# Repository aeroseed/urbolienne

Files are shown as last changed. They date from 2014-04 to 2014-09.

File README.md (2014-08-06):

urbolienne
==========

You will find on this webpage all the documents relative to the [AeroSeeD](http://www.aeroseed.com)'s wind turbine (the "urbolienne").

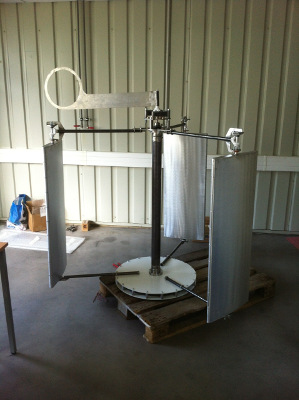
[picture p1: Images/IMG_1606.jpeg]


The Urbolienne Project website : http://www.energinov.org

Licenses
--------

<a href="http://www.oshwa.org/definition/">Prototype of urbolienne</a>

The urbolienne's 2D drawings and 3D models are made available under the terms of the TAPR Open Hardware License (http://tapr.org/ohl). See the "TAPR license.txt" file that accompanies this distribution for the full text of the license.

The urbolienne's documentation is made available under the terms of the GNU Free Documentation Licence (https://www.gnu.org/licenses/fdl.html). See the "GNU Free Documentation License.txt" file that accompanies this distribution for the full text of the license.

Disclaimer
----------

This hardware/software is provided "as is", and you use the hardware/software at your own risk. Under no circumstances shall any author be liable for direct, indirect, special, incidental, or consequential damages resulting from the use, misuse, or inability to use this hardware/software, even if the authors have been advised of the possibility of such damages.

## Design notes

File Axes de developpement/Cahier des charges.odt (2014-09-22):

Cahier des charges fonctionnel

pour la mise au point d'un produit commercialisable de l'

Eolienne à orientation de pale dynamique

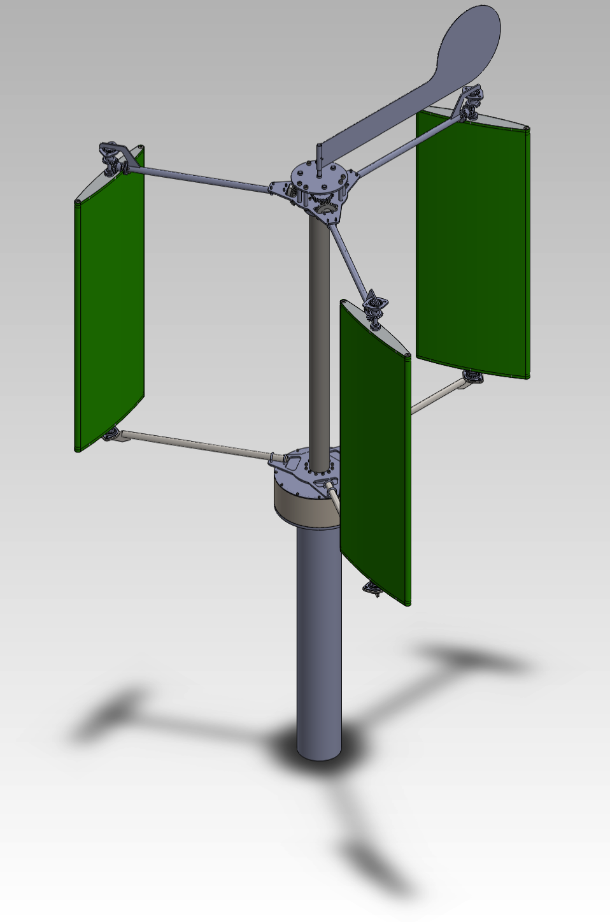
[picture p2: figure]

1. Objet du document :

Ce document décrit les axes de développements pour l'obtention d'un produit commercialisable.

LICENCE :

Licenced under the GNU Free documentation Licence (https://www.gnu.org/licenses/fdl.fr.html)

Cahier des charges

Théophile BRESSON - AeroSeeD Page 1 sur 1 03/07/2014

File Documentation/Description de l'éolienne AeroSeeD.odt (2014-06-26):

Copyright (C) 2014 Théophile BRESSON - AeroSeeD.

Permission is granted to copy, distribute and/or modify this document under the terms of the GNU Free Documentation License, Version 1.3 or any later version published by the Free Software Foundation;

with no Invariant Sections, no Front-Cover Texts, and no Back-Cover Texts.

A copy of the license is included in the section entitled "GNU Free Documentation License".

Éolienne à orientation de pale dynamique


1. Objet du document :

Ce document décrit ce qui caractérise l'éolienne d'AeroSeeD...

2. Idée :

L’éolienne proposée présente l’intérêt suivant :

Cette éolienne est capable de produire de l’énergie avec un rendement plus élevé que les éoliennes actuelles dans des conditions d'installation en écoulement turbulent (villes ou villages).

Nous avons abouti à une éolienne à axe vertical dont les pales lors de leur rotation s’orientent par rapport au vent de manière à fournir à l’éolienne le maximum de puissance.

3. Historique du développement

Courant 2005 : discussions avec Richard SORRENTINO à propos d’une éolienne à pas variable du même type que celle déjà existante (voir brevet nommé précédemment).

04/08/2007 : réalisation d’une maquette en lego du système pour observer le fonctionnement et test à l’aide d’un ventilateur.

19/08/2007 : premier tableau grossier permettant le calcul de la puissance délivrée par l’éolienne en fonction de ses dimensions et de la vitesse du vent.

10/07/2008 : réalisation d’une première CAO de l’éolienne afin de se confronter à la faisabilité du projet et terme mécanique.
Réalisation d’un premier chiffrage du modèle CAO de manière à quantifier la fabrication du prototype, il manque alors toute la partie électrique de puissance.

Courant été 2008 : découverte de l’idée d’une cinématique de pale calée de manière à maximiser la puissance.

05/12/2008 : première simulation fluide menée via le logiciel Fluent d’ANSYS.

18/04/2009 : développement d’un logiciel en C++ de manière à quantifier le gain théorique que permet ce calage de la pale et apparition des premières théories cinématiques du mouvement (adaptation d’un mouvement sinusoïdal de la pale autour de sa position « standard »).

12/05/2010 : deuxième simulation fluide de l’éolienne de manière à prendre en compte les modifications apportées et quantifier les turbulences générées par la pale amont sur la pale aval.

10/03/2011 : réalisation d’un deuxième tableau de manière à quantifier la puissance produite par l’éolienne avec et sans l’innovation. Comparatif permettant de montrer une multiplication de la production énergétique par deux (2).

12/03/2011 : réalisation d’un premier modèle de CAO destiné à être le support des plans de fabrication du premier prototype.
L’entraînement des pales sera réalisé par un système de pignon/chaîne/roue dentée elliptique.
Ajout d’un système de mise en sécurité de l’éolienne reposant sur le principe du régulateur de WATT.

29/07/2011 : réalisation d’une nouvelle simulation fluide. Celle-ci permet de quantifier avec une bonne approximation la puissance produite par l’éolienne. Nous avons ainsi pu estimer son rendement aérodynamique théorique dans l’état « brut » (sans optimisation de profil de pale ni de géométrie).

24/11/2011 : modification de la conception du modèle de CAO de manière à le simplifier et le rendre plus robuste.
Modification du système d’entraînement des pales qui sera réalisé par un jeu d’engrenage conique ainsi que d’engrenage elliptique. L’ellipse étant déterminée de manière à être la plus proche de la cinématique optimale et ainsi maximiser la puissance produite (voir Annexe 2).
Modification du système de mise en sécurité.

Début 2014 : suite au choix de développer l'éolienne sous licence libre, les outils nécessaires au support de la communauté ont été mis en place et étayés.

4. Description :

L'éolienne est équipée d’une voilure tournante comprenant :

- Un axe principal (vertical) permettant le guidage du rotor ;
- Une girouette ;
- 3 pales ;
- 3 bras inférieurs et 3 bras supérieurs de maintien des pales ;
- L'orientation des pales est imposée par la girouette via un système d'engrenages et d'arbres de transmission ;
- Un alternateur, pour transformer l'énergie mécanique en énergie électrique.

La transmission de chaque pale est réalisée de manière à ce que celle-ci effectue une demi révolution autour de son axe lorsque le rotor réalise une révolution autour de son axe.

L’orientation de chaque pale par rapport à la girouette est réalisée de manière à maximiser la puissance de cette pale en chaque point lors de sa révolution autour du rotor.

5. Théorie du mouvement :

L’orientation théorique de la pale à chaque position lors de sa rotation autour du rotor est déterminée par un tableau combiné à une simulation d’écoulement fluide de manière à connaître la trajectoire de la pale.
Le rapport moyen sur un tour de la rotation de la pale par rapport à celle du rotor est égal à un demi (0,5).
Le rapport instantané à chaque position de la pale lors de sa révolution autour de l’éolienne entre la pale et le rotor, varie entre 0,25 et 4 et plus précisément dans l’état de nos recherche entre 0,4 et 2,5.

La partie difficile ayant été de déterminer un mécanisme réel permettant de caler parfaitement à cette cinématique et sinon de s’en approcher le plus possible.

Les parties suivantes vont présenter à la fois une description de l’idée proprement dite et sujette de ce document, ainsi que les choix technologiques que nous avons posés afin de fabriquer un prototype nous permettant de valider cette idée.

6. Théorie aérodynamique :

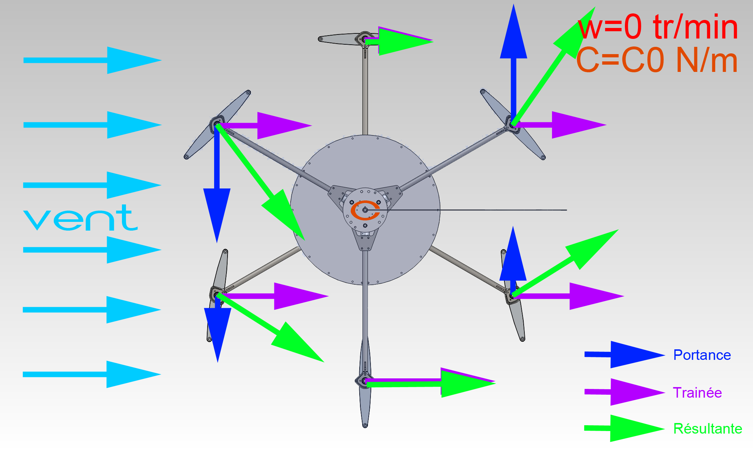
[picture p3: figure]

Bilan des efforts appliqués sur la pale suivant plusieurs positions lors de sa révolution autour de l'axe pour une vitesse de vent Vn (m/s) et pour une vitesse de rotation nulle.

Cette configuration permet d'obtenir un couple minium permettant à l'éolienne de commencer à tourner lorsque le vent se lève.

Ensuite, c'est l'orientation des pales spécialement étudié par AeroSeeD qui permet d'obtenir une vitesse nominale importante (la pale initialement poussée allant à la même vitesse que le vent). Tout en conservant un couple résultant par portance de la pale lors de sa trajectoire transverse (voir images ci-après).

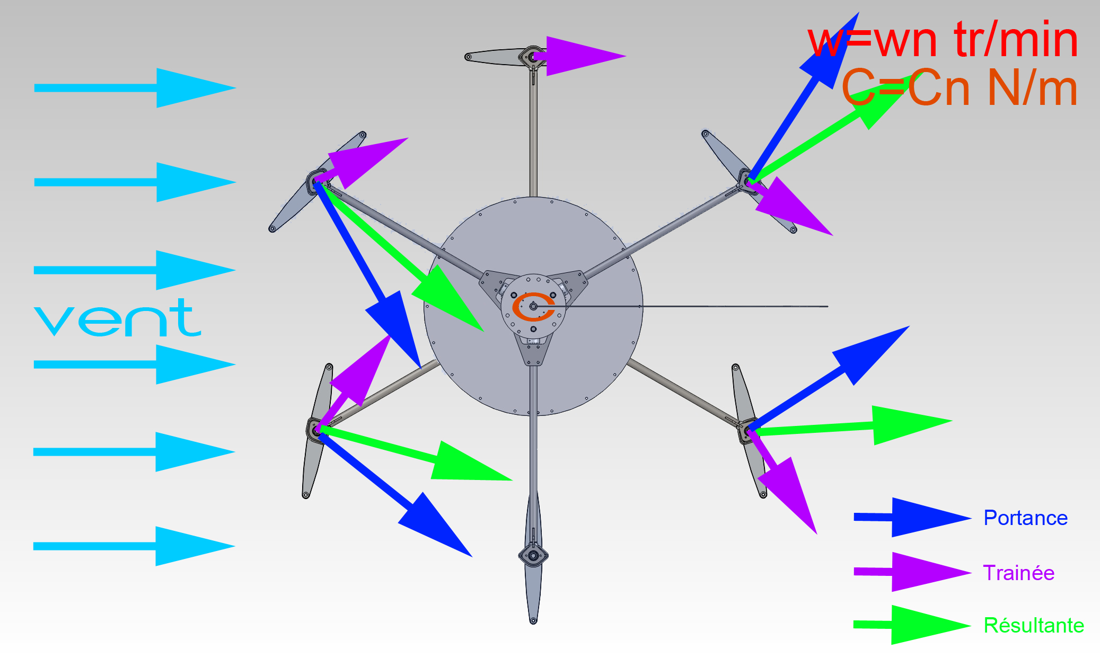
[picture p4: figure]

On obtient alors un fonctionnement basé sur la portance des pales et non plus sur la traînée ce qui permet d'augmenter la vitesse et le couple résultant de l'éolienne.

Ces deux points de fonctionnements sont mis en valeur sur la courbe calculée du couple en fonction de la vitesse de rotation pour une vitesse de vent de 10m/s :

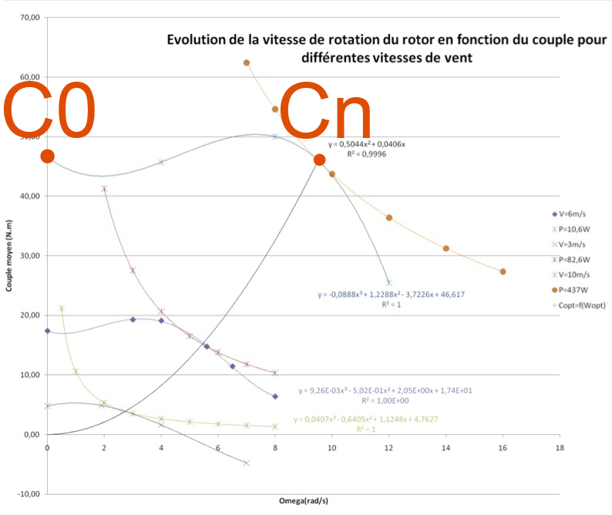
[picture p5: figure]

Nous estimons (par simulation numérique) avoir ainsi pu pousser le rendement aérodynamique de l'éolienne à 43 % théorique.

Cela veut simplement dire que pour 1kW d'énergie contenue dans le vent, nous collectons 430W.

7. GNU Free Documentation License

Le texte de la licence GNU Free Documentation License est disponible sur la page Web https://www.gnu.org/licenses/fdl.fr.html

Description de l'éolienne d'AeroSeeD

Page 7 sur 7 26/06/2014

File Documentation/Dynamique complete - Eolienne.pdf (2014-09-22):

Pour%une%éolienne%3%pales%de%0,4m%de%corde%et%de%1m%de%haut%sur%un%rayon%de%0,7

V%vent%(m/s) Puissance%th.%Dans%le%vent%(w) Limite%de%Betz Omega%(rad/s) | tr/min | Couple%aero%(N.m) Puissance%aero%(W)rendement%aéro Anti%couple%entrainement%des%pales%(N.m) Couple%resultant%(N.m)
0 | 0 | 0 | 0 | 0 | 0 | 0 | #DIV/0! | 0 | 0
1,0683 | 1,03267365 0,611954755 | 1 | 19,09859317 | 0,545 | 0,545 | 0,527756276 | 0,026 | 0,519
2,1366 | 8,261389199 4,895638044 | 2 | 38,19718634 | 2,0988 | 4,1976 | 0,508098565 | 0,104 | 1,9948
3,2049 | 27,88218855 | 16,5227784 | 3 | 57,29577951 | 4,6614 | 13,9842 | 0,501545995 | 0,234 | 4,4274
4,2732 | 66,09111359 39,16510435 | 4 | 76,39437268 | 8,2328 | 32,9312 | 0,49826971 | 0,416 | 7,8168
5,3415 | 129,0842062 76,49434443 | 5 | 95,49296586 | 12,813 | 64,065 | 0,496303939 | 0,65 | 12,163
6,4098 | 223,0575084 132,1822272 | 6 | 114,591559 | 18,402 | 110,412 | 0,494993425 | 0,936 | 17,466
7,4781 | 354,2070619 209,9004811 | 7 | 133,6901522 | 24,9998 | 174,9986 | 0,494057343 | 1,273 | 23,7268
8,5464 | 528,7289087 313,3208348 | 8 | 152,7887454 | 32,6064 | 260,8512 | 0,493355282 | 1,663 | 30,9434
9,6147 | 752,8190907 446,1150167 | 9 | 171,8873385 | 41,2218 | 370,9962 | 0,492809235 | 2,105 | 39,1168
10,683 | 1032,67365 611,9547555 | 10 | 190,9859317 | 50,846 | 508,46 | 0,492372397 | 2,599 | 48,247
11,7513 | 1374,488628 814,5117795 | 11 | 210,0845249 | 61,479 | 676,269 | 0,492014984 | 3,145 | 58,334
12,8196 | 1784,460067 1057,457817 | 12 | 229,1831181 | 73,1208 | 877,4496 | 0,49171714 | 3,742 | 69,3788
13,8879 | 2268,784009 1344,464598 | 13 | 248,2817112 | 85,7714 | 1115,0282 | 0,491465118 | 4,392 | 81,3794
14,9562 | 2833,656495 1679,203849 | 14 | 267,3803044 | 99,4308 | 1392,0312 | 0,491249099 | 5,094 | 94,3368
16,0245 | 3485,273568 | 2065,3473 | 15 | 286,4788976 | 114,099 | 1711,485 | 0,491061883 | 5,848 | 108,251
17,0928 | 4229,83127 2506,566678 | 16 | 305,5774907 | 129,776 | 2076,416 | 0,490898068 | 6,653 | 123,123
18,1611 | 5073,525642 3006,533714 | 17 | 324,6760839 | 146,4618 | 2489,8506 | 0,490753526 | 7,511 | 138,9508
19,2294 | 6022,552726 3568,920134 | 18 | 343,7746771 | 164,1564 | 2954,8152 | 0,490625045 | 8,421 | 155,7354
20,2977 | 7083,108564 4197,397668 | 19 | 362,8732702 | 182,8598 | 3474,3362 | 0,490510087 | 9,382 | 173,4778
21,366 | 8261,389199 4895,638044 | 20 | 381,9718634 | 202,572 | 4051,44 | 0,490406626 | 10,396 | 192,176

STK2M
tr/min | rad/s | couple%admissible%(N.m) Pu%nominal
0 | 0 | 0 | 0
50 | 5,235987756 | 40 | 250
100 | 10,47197551 | 75 | 675
150 | 15,70796327 | 95 | 1100
200 | 20,94395102 | 100 | 1600

Document%appartenant%à%AeroSeeD Sous%Licence%Creative%Commons%Attribution%Y%Partage%dans%les%Mêmes%Conditions%2.0%France.

y%=%Y0,2147x²%+%
9,3183x%
R²%=%0,99816%

y%=%Y0,0602x³%+%
3,2114x²%+%35,349x%
R²%=%0,99945%

0%

200%

400%

600%

800%

1000%

1200%

1400%

1600%

1800%

0% | 10% | 20% | 30%

couple%
admissible%
(N.m)%
Pu%nominal%

Poly.%(couple%
admissible%
(N.m))%
Poly.%(Pu%
nominal)%
0%

50%

100%

150%

200%

250%

300%

350%

400%

0% | 2% | 4% | 6% | 8% | 10%

Limite%de%Betz%

Puissance%electrique%
alternateur%(W)%

Puisance%mécanique%resultante%(W) rendement%méca Rendement%electrique Puissance%electrique%alternateur%(W) rendement%elec%alternateur Rendement%onduleur Puissance%utile%(W) rendement%utile
0 | #DIV/0! | 0,8 | 0 | #DIV/0! | 0,91 | 0 | #DIV/0!
0,519 | 0,502578913 | 0,8 | 0,4152 | 0,40206313 | 0,91 | 0,377832 | 0,365877448
3,9896 | 0,482921202 | 0,8 | 3,19168 | 0,386336961 | 0,91 | 2,9044288 | 0,351566635
13,2822 | 0,476368631 | 0,8 | 10,62576 | 0,381094905 | 0,91 | 9,6694416 | 0,346796364
31,2672 | 0,473092346 | 0,8 | 25,01376 | 0,378473877 | 0,91 | 22,7625216 | 0,344411228
60,815 | 0,471126575 | 0,8 | 48,652 | 0,37690126 | 0,91 | 44,27332 | 0,342980147
104,796 | 0,469816061 | 0,8 | 83,8368 | 0,375852849 | 0,91 | 76,291488 | 0,342026093
166,0876 | 0,468899742 | 0,8 | 132,87008 | 0,375119794 | 0,91 | 120,9117728 | 0,341359012
247,5472 | 0,468193049 | 0,8 | 198,03776 | 0,374554439 | 0,91 | 180,2143616 | 0,34084454
352,0512 | 0,467643826 | 0,8 | 281,64096 | 0,374115061 | 0,91 | 256,2932736 | 0,340444705
482,47 | 0,467204717 | 0,8 | 385,976 | 0,373763773 | 0,91 | 351,23816 | 0,340125034
641,674 | 0,466845623 | 0,8 | 513,3392 | 0,373476499 | 0,91 | 467,138672 | 0,339863614
832,5456 | 0,466553225 | 0,8 | 626,0832 | 0,350853018 | 0,91 | 569,735712 | 0,319276246
1057,9322 | 0,466299214 | 0,8 | 696,00336 | 0,306773742 | 0,91 | 633,3630576 | 0,279164105
1320,7152 | 0,466081617 | 0,8 | 767,30528 | 0,270782744 | 0,91 | 698,2478048 | 0,246412297
1623,765 | 0,465893127 | 0,8 | 839,7 | 0,240928003 | 0,91 | 764,127 | 0,219244483
1969,968 | 0,465732053 | 0,8 | 912,89856 | 0,215823871 | 0,91 | 830,7376896 | 0,196399723
2362,1636 | 0,465586215 | 0,8 | 986,612 | 0,1944628 | 0,91 | 897,81692 | 0,176961148
2803,2372 | 0,465456647 | 0,8 | 1060,55136 | 0,17609665 | 0,91 | 965,1017376 | 0,160247952
3296,0782 | 0,465343453 | 0,8 | 1134,42768 | 0,160159578 | 0,91 | 1032,329189 | 0,145745216
3843,52 | 0,465238946 | 0,8 | 1207,952 | 0,146216571 | 0,91 | 1099,23632 | 0,13305708

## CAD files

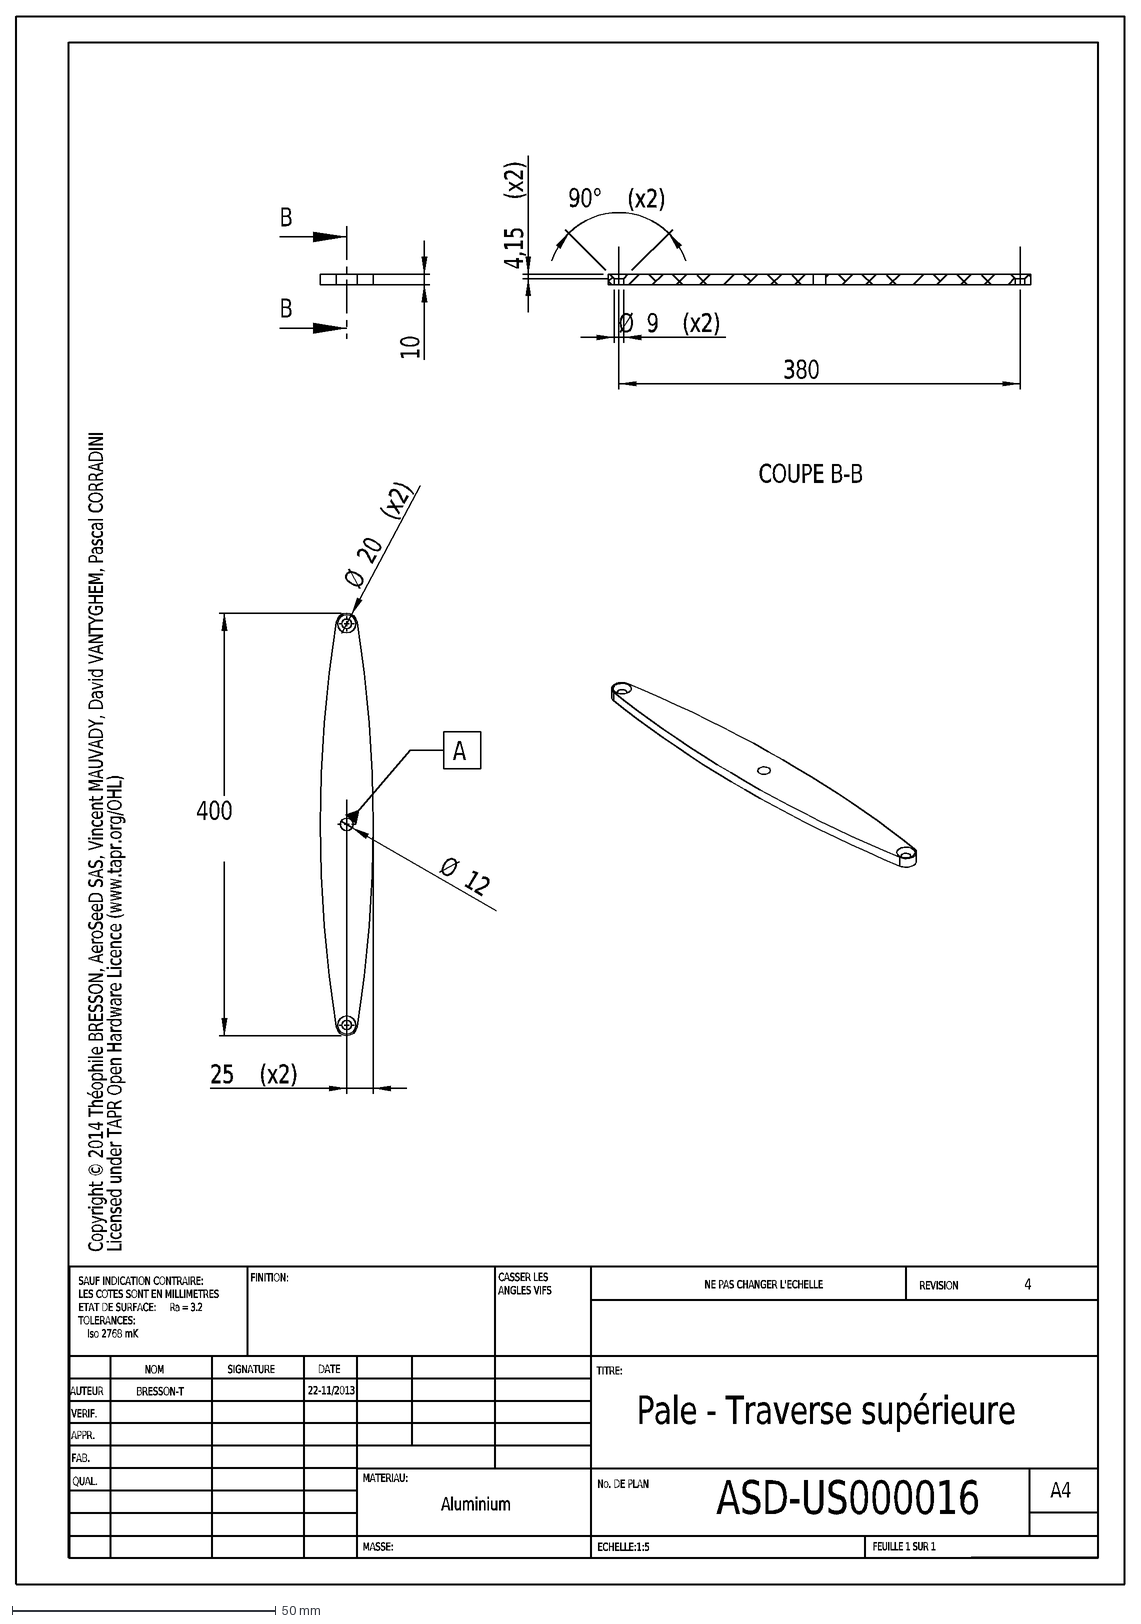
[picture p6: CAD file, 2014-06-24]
2D drawings/DXF/ASD-US000016 - traverse pale-superieure.DXF
Copyright © 2014 Théophile BRESSON, AeroSeeD SAS, Vincent MAUVADY, David VANTYGHEM, Pascal CORRADINI
Licensed under TAPR Open Hardware Licence (www.tapr.org/OHL)
4
Pale - Traverse supérieure
ASD-US000016
22-11/2013
BRESSON-T
MASSE:
Aluminium
A4
FEUILLE 1 SUR 1
ECHELLE:1:5
No. DE PLAN
TITRE:
REVISION
NE PAS CHANGER L'ECHELLE
MATERIAU:
DATE
SIGNATURE
NOM
CASSER LES
ANGLES VIFS
FINITION:
QUAL.
FAB.
APPR.
VERIF.
AUTEUR
SAUF INDICATION CONTRAIRE:
LES COTES SONT EN MILLIMETRES
ETAT DE SURFACE:
Ra = 3.2
TOLERANCES:
Iso 2768 mK
10
B
400
Ø
20
(x2)
25
12
A
380
9
90°
4,15
COUPE B-B

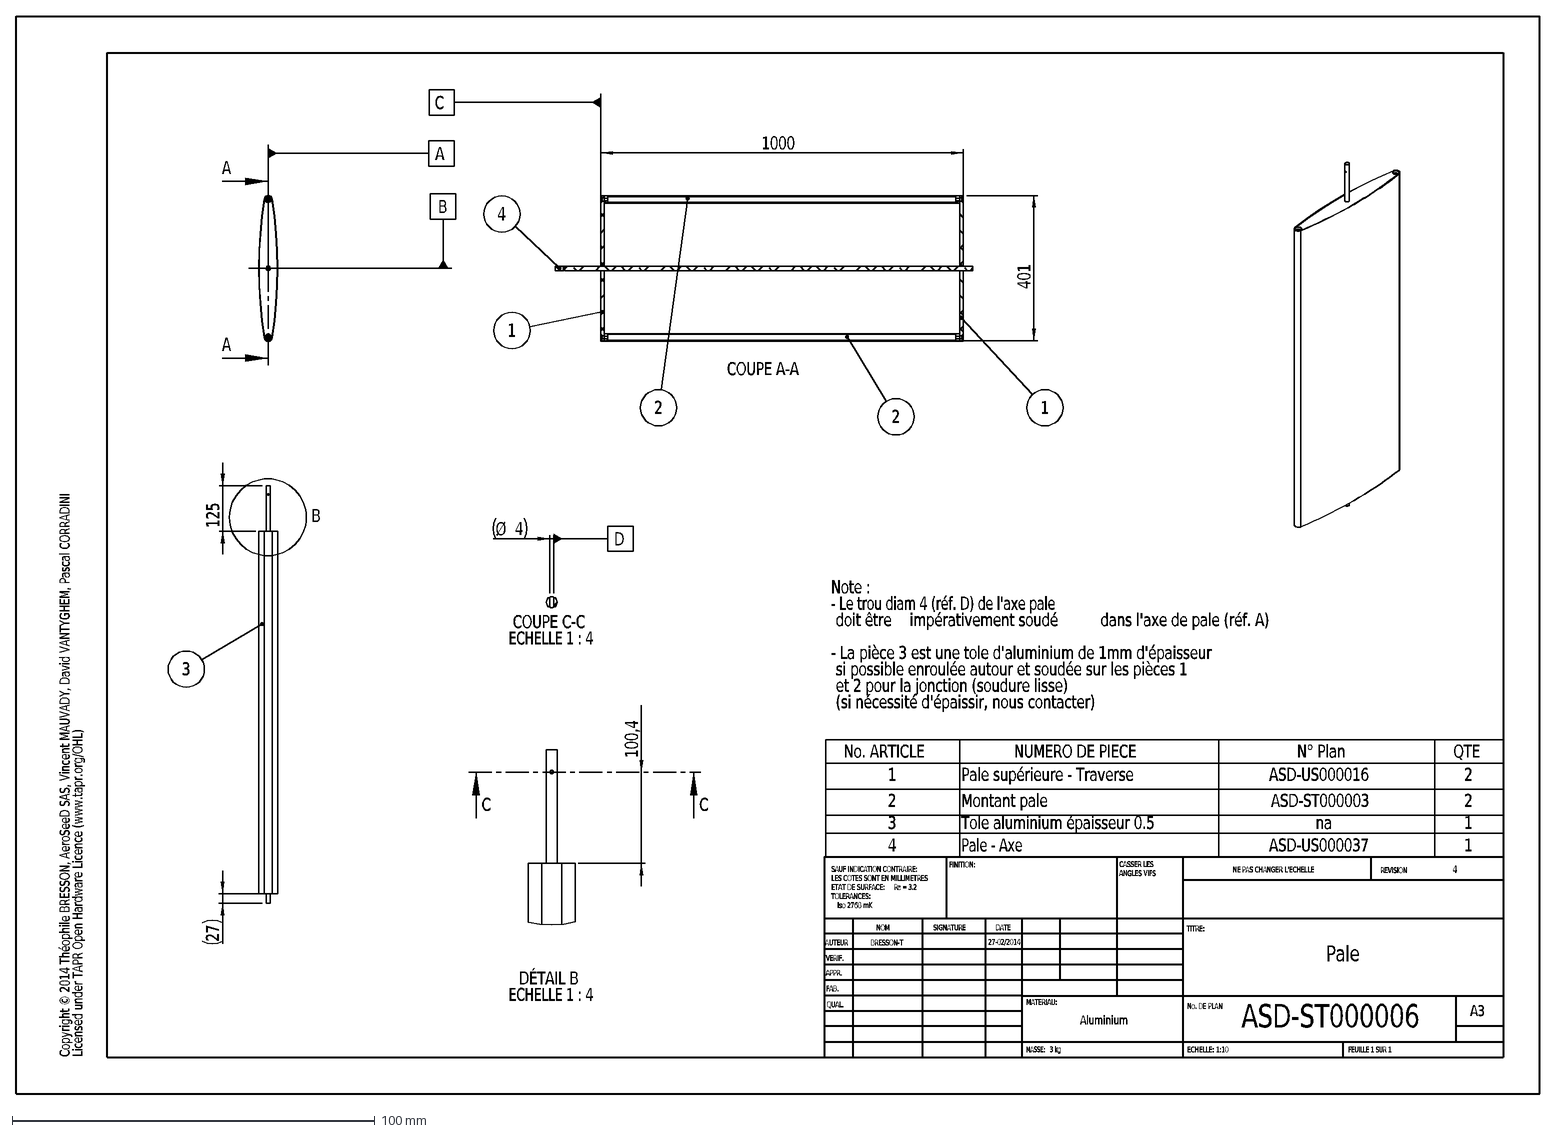
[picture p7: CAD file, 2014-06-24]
2D drawings/DXF/ASD-ST000006 - Pale.DXF
Note :
- Le trou diam 4 (réf. D) de l'axe pale
doit être
impérativement soudé
dans l'axe de pale (réf. A)
- La pièce 3 est une tole d'aluminium de 1mm d'épaisseur
si possible enroulée autour et soudée sur les pièces 1
et 2 pour la jonction (soudure lisse)
(si nécessité d'épaissir, nous contacter)
Copyright © 2014 Théophile BRESSON, AeroSeeD SAS, Vincent MAUVADY, David VANTYGHEM, Pascal CORRADINI
Licensed under TAPR Open Hardware Licence (www.tapr.org/OHL)
4
Pale
ASD-ST000006
27-02/2014
BRESSON-T
MASSE: 3 kg
Aluminium
A3
FEUILLE 1 SUR 1
ECHELLE: 1:10
No. DE PLAN
TITRE:
REVISION
NE PAS CHANGER L'ECHELLE
MATERIAU:
DATE
SIGNATURE
NOM
CASSER LES
ANGLES VIFS
FINITION:
QUAL.
FAB.
APPR.
VERIF.
AUTEUR
SAUF INDICATION CONTRAIRE:
LES COTES SONT EN MILLIMETRES
ETAT DE SURFACE:
Ra = 3.2
TOLERANCES:
Iso 2768 mK
No. ARTICLE
NUMERO DE PIECE
N° Plan
QTE
1
Pale supérieure - Traverse
ASD-US000016
2
Montant pale
ASD-ST000003
3
Tole aluminium épaisseur 0.5
na
Pale - Axe
ASD-US000037
125
27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

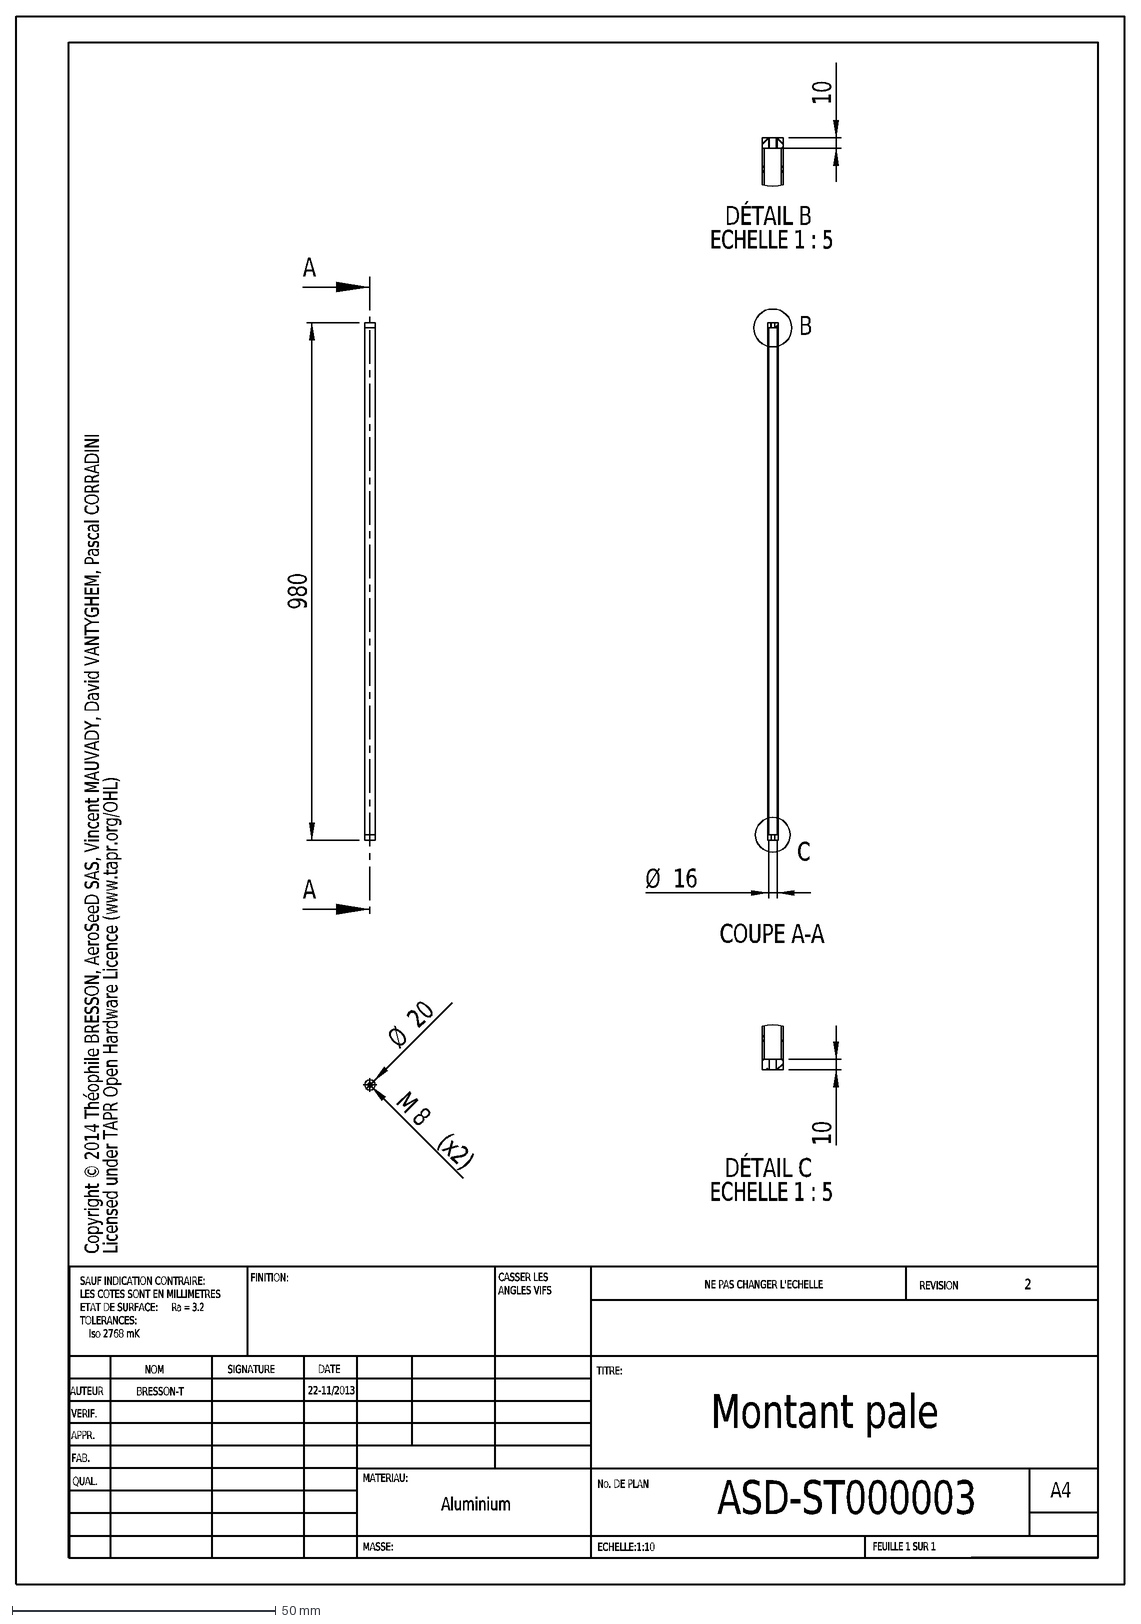
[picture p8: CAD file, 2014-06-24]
2D drawings/DXF/ASD-ST000003 - Montant pale.DXF
Copyright © 2014 Théophile BRESSON, AeroSeeD SAS, Vincent MAUVADY, David VANTYGHEM, Pascal CORRADINI
Licensed under TAPR Open Hardware Licence (www.tapr.org/OHL)
2
Montant pale
ASD-ST000003
22-11/2013
BRESSON-T
MASSE:
Aluminium
A4
FEUILLE 1 SUR 1
ECHELLE:1:10
No. DE PLAN
TITRE:
REVISION
NE PAS CHANGER L'ECHELLE
MATERIAU:
DATE
SIGNATURE
NOM
CASSER LES
ANGLES VIFS
FINITION:
QUAL.
FAB.
APPR.
VERIF.
AUTEUR
SAUF INDICATION CONTRAIRE:
LES COTES SONT EN MILLIMETRES
ETAT DE SURFACE:
Ra = 3.2
TOLERANCES:
Iso 2768 mK
980
A
Ø
20
M
8
(x2)
16
COUPE A-A
B
C
10
DÉTAIL B
ECHELLE 1 : 5
DÉTAIL C

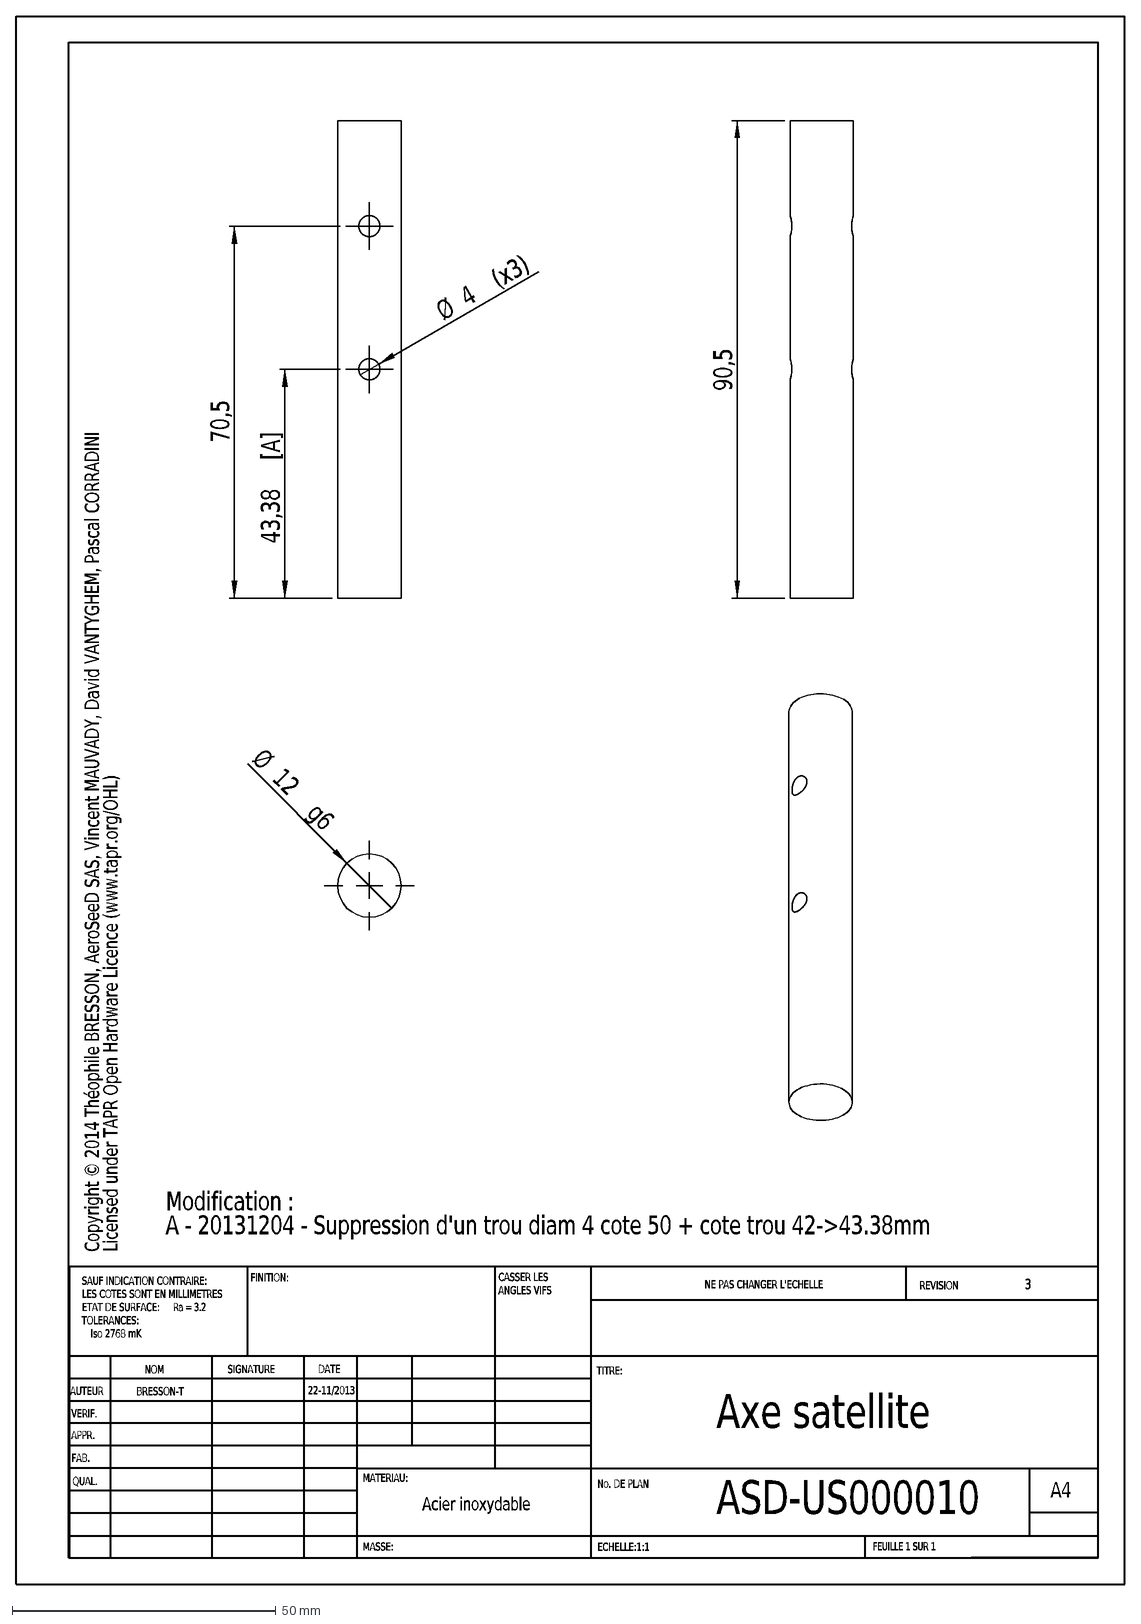
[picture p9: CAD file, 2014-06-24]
2D drawings/DXF/ASD-US000010 - Axe-satellite.DXF
Modification :
A - 20131204 - Suppression d'un trou diam 4 cote 50 + cote trou 42->43.38mm
Copyright © 2014 Théophile BRESSON, AeroSeeD SAS, Vincent MAUVADY, David VANTYGHEM, Pascal CORRADINI
Licensed under TAPR Open Hardware Licence (www.tapr.org/OHL)
3
Axe satellite
ASD-US000010
22-11/2013
BRESSON-T
MASSE:
Acier inoxydable
A4
FEUILLE 1 SUR 1
ECHELLE:1:1
No. DE PLAN
TITRE:
REVISION
NE PAS CHANGER L'ECHELLE
MATERIAU:
DATE
SIGNATURE
NOM
CASSER LES
ANGLES VIFS
FINITION:
QUAL.
FAB.
APPR.
VERIF.
AUTEUR
SAUF INDICATION CONTRAIRE:
LES COTES SONT EN MILLIMETRES
ETAT DE SURFACE:
Ra = 3.2
TOLERANCES:
Iso 2768 mK
43,38
[A]
70,5
Ø
4
(x3)
90,5
12
g6

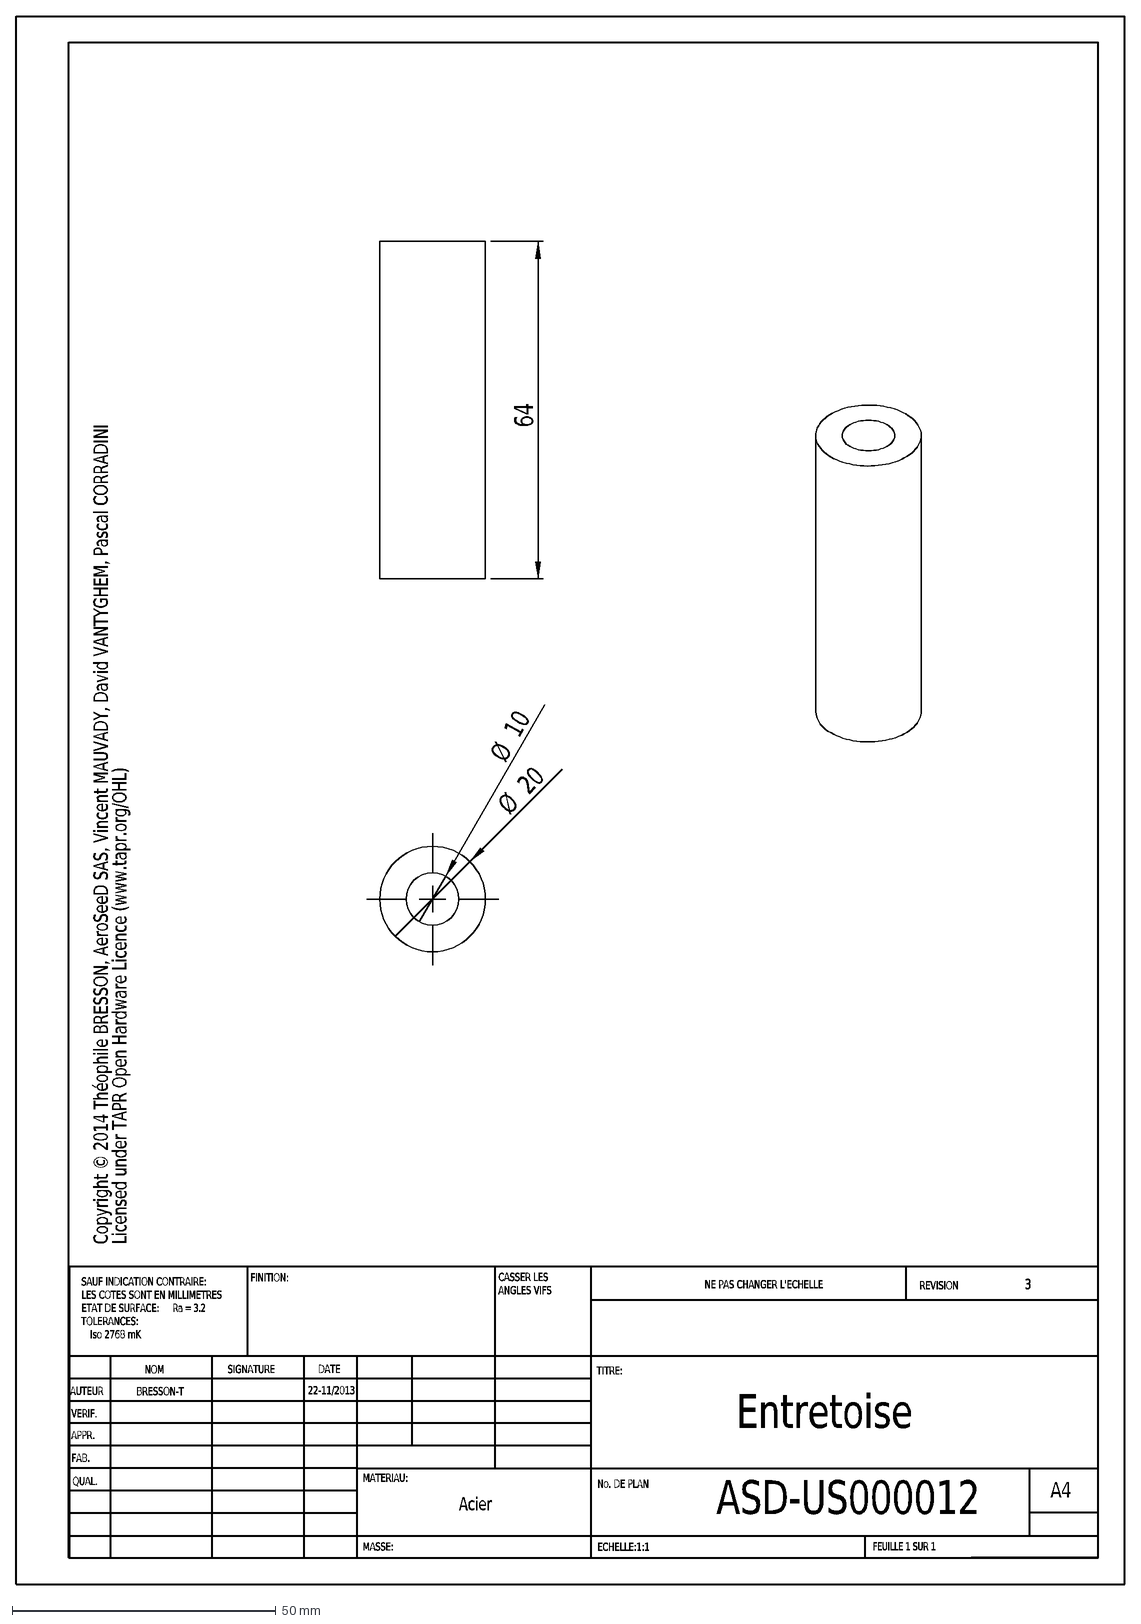
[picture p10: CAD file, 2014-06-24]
2D drawings/DXF/ASD-US000012 - entretoise.DXF
Copyright © 2014 Théophile BRESSON, AeroSeeD SAS, Vincent MAUVADY, David VANTYGHEM, Pascal CORRADINI
Licensed under TAPR Open Hardware Licence (www.tapr.org/OHL)
3
Entretoise
ASD-US000012
22-11/2013
BRESSON-T
MASSE:
Acier
A4
FEUILLE 1 SUR 1
ECHELLE:1:1
No. DE PLAN
TITRE:
REVISION
NE PAS CHANGER L'ECHELLE
MATERIAU:
DATE
SIGNATURE
NOM
CASSER LES
ANGLES VIFS
FINITION:
QUAL.
FAB.
APPR.
VERIF.
AUTEUR
SAUF INDICATION CONTRAIRE:
LES COTES SONT EN MILLIMETRES
ETAT DE SURFACE:
Ra = 3.2
TOLERANCES:
Iso 2768 mK
64
Ø
20
10

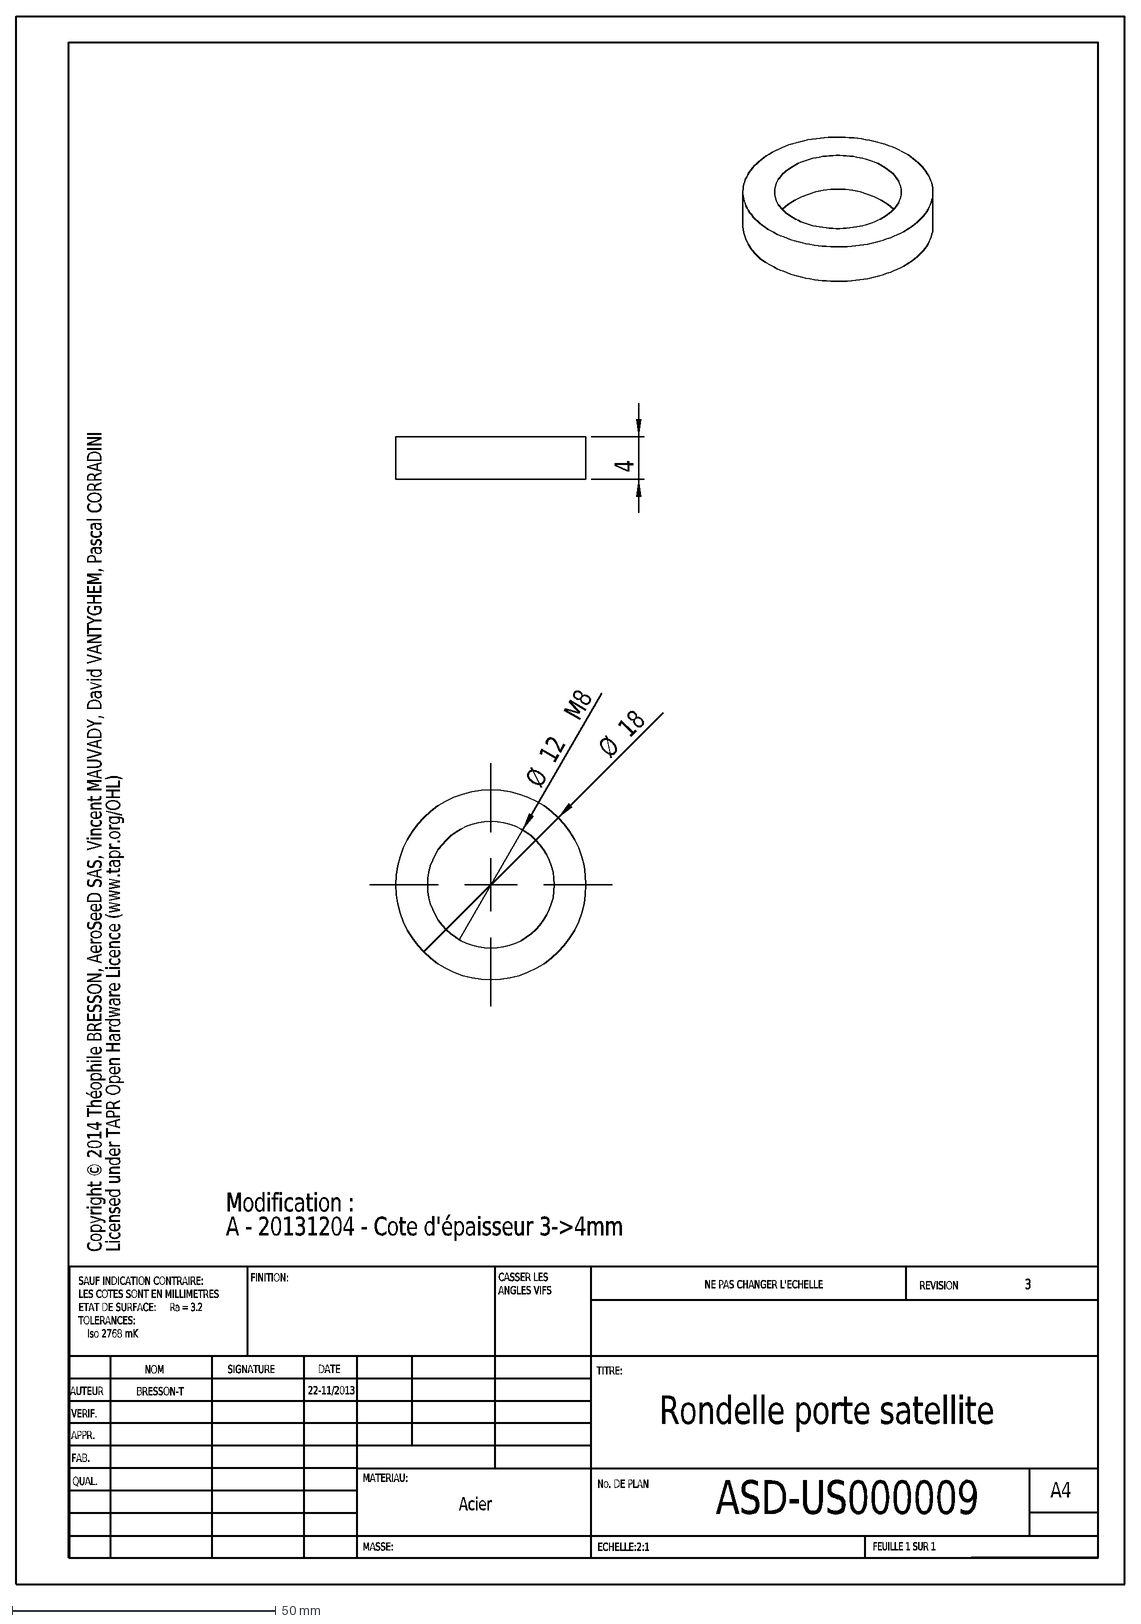
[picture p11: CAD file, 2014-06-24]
2D drawings/DXF/ASD-US000009 - Rondelle-PorteSatellite.DXF
Modification :
A - 20131204 - Cote d'épaisseur 3->4mm
Copyright © 2014 Théophile BRESSON, AeroSeeD SAS, Vincent MAUVADY, David VANTYGHEM, Pascal CORRADINI
Licensed under TAPR Open Hardware Licence (www.tapr.org/OHL)
3
Rondelle porte satellite
ASD-US000009
22-11/2013
BRESSON-T
MASSE:
Acier
A4
FEUILLE 1 SUR 1
ECHELLE:2:1
No. DE PLAN
TITRE:
REVISION
NE PAS CHANGER L'ECHELLE
MATERIAU:
DATE
SIGNATURE
NOM
CASSER LES
ANGLES VIFS
FINITION:
QUAL.
FAB.
APPR.
VERIF.
AUTEUR
SAUF INDICATION CONTRAIRE:
LES COTES SONT EN MILLIMETRES
ETAT DE SURFACE:
Ra = 3.2
TOLERANCES:
Iso 2768 mK
4
Ø
18
12
M8

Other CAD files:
2D drawings/DXF/ASD-US000029 - Alternateur-rotor-CORADINI-plateau-inferieur.DXF
2D drawings/DXF/ASD-US000036 - Plateau-Axe-fixe.DXF
2D drawings/DXF/ASD-ST000002 - Bras inferieur.DXF
2D drawings/DXF/ASD-US000011 - EE200-25.DXF
2D drawings/DXF/ASD-US000030 - Alternateur-rotor-CORADINI-entretoise.DXF
2D drawings/DXF/ASD-ST000004 - Bras superieur.DXF
2D drawings/DXF/ASD-US000028 - Alternateur-rotor-CORADINI.DXF
2D drawings/DXF/ASD-ST000001 - Axe fixe rotor.DXF
2D drawings/DXF/ASD-US000013 - Porte-satellite.DXF
2D drawings/DXF/ASD-US000027 - Bobinage generatrice.DXF
2D drawings/DXF/ASD-US000014 - Girouette.DXF
2D drawings/DXF/ASD-US000037 - Axe-Pale.DXF
2D drawings/DXF/ASD-ST000005 - Axe-rotor+Porte-platine.DXF
2D drawings/DXF/ASD-US000008 - platine superieur.DXF
2D drawings/DXF/ASD-US000015 - Axe-girouette.DXF
2D drawings/DXF/ASD-US000031 - Arbre-transmission-pale.DXF

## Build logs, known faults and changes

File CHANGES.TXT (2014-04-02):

You must identify the modifications in this text file.
These modifications are licensed under the TAPR Open Hardware License.

-----BEGINING OF THE MODIFICATIONS-----

	-2014/04/02 - Theophile Bresson
	First Release
	
	-

-----END OF THE MODIFICATIONS-----

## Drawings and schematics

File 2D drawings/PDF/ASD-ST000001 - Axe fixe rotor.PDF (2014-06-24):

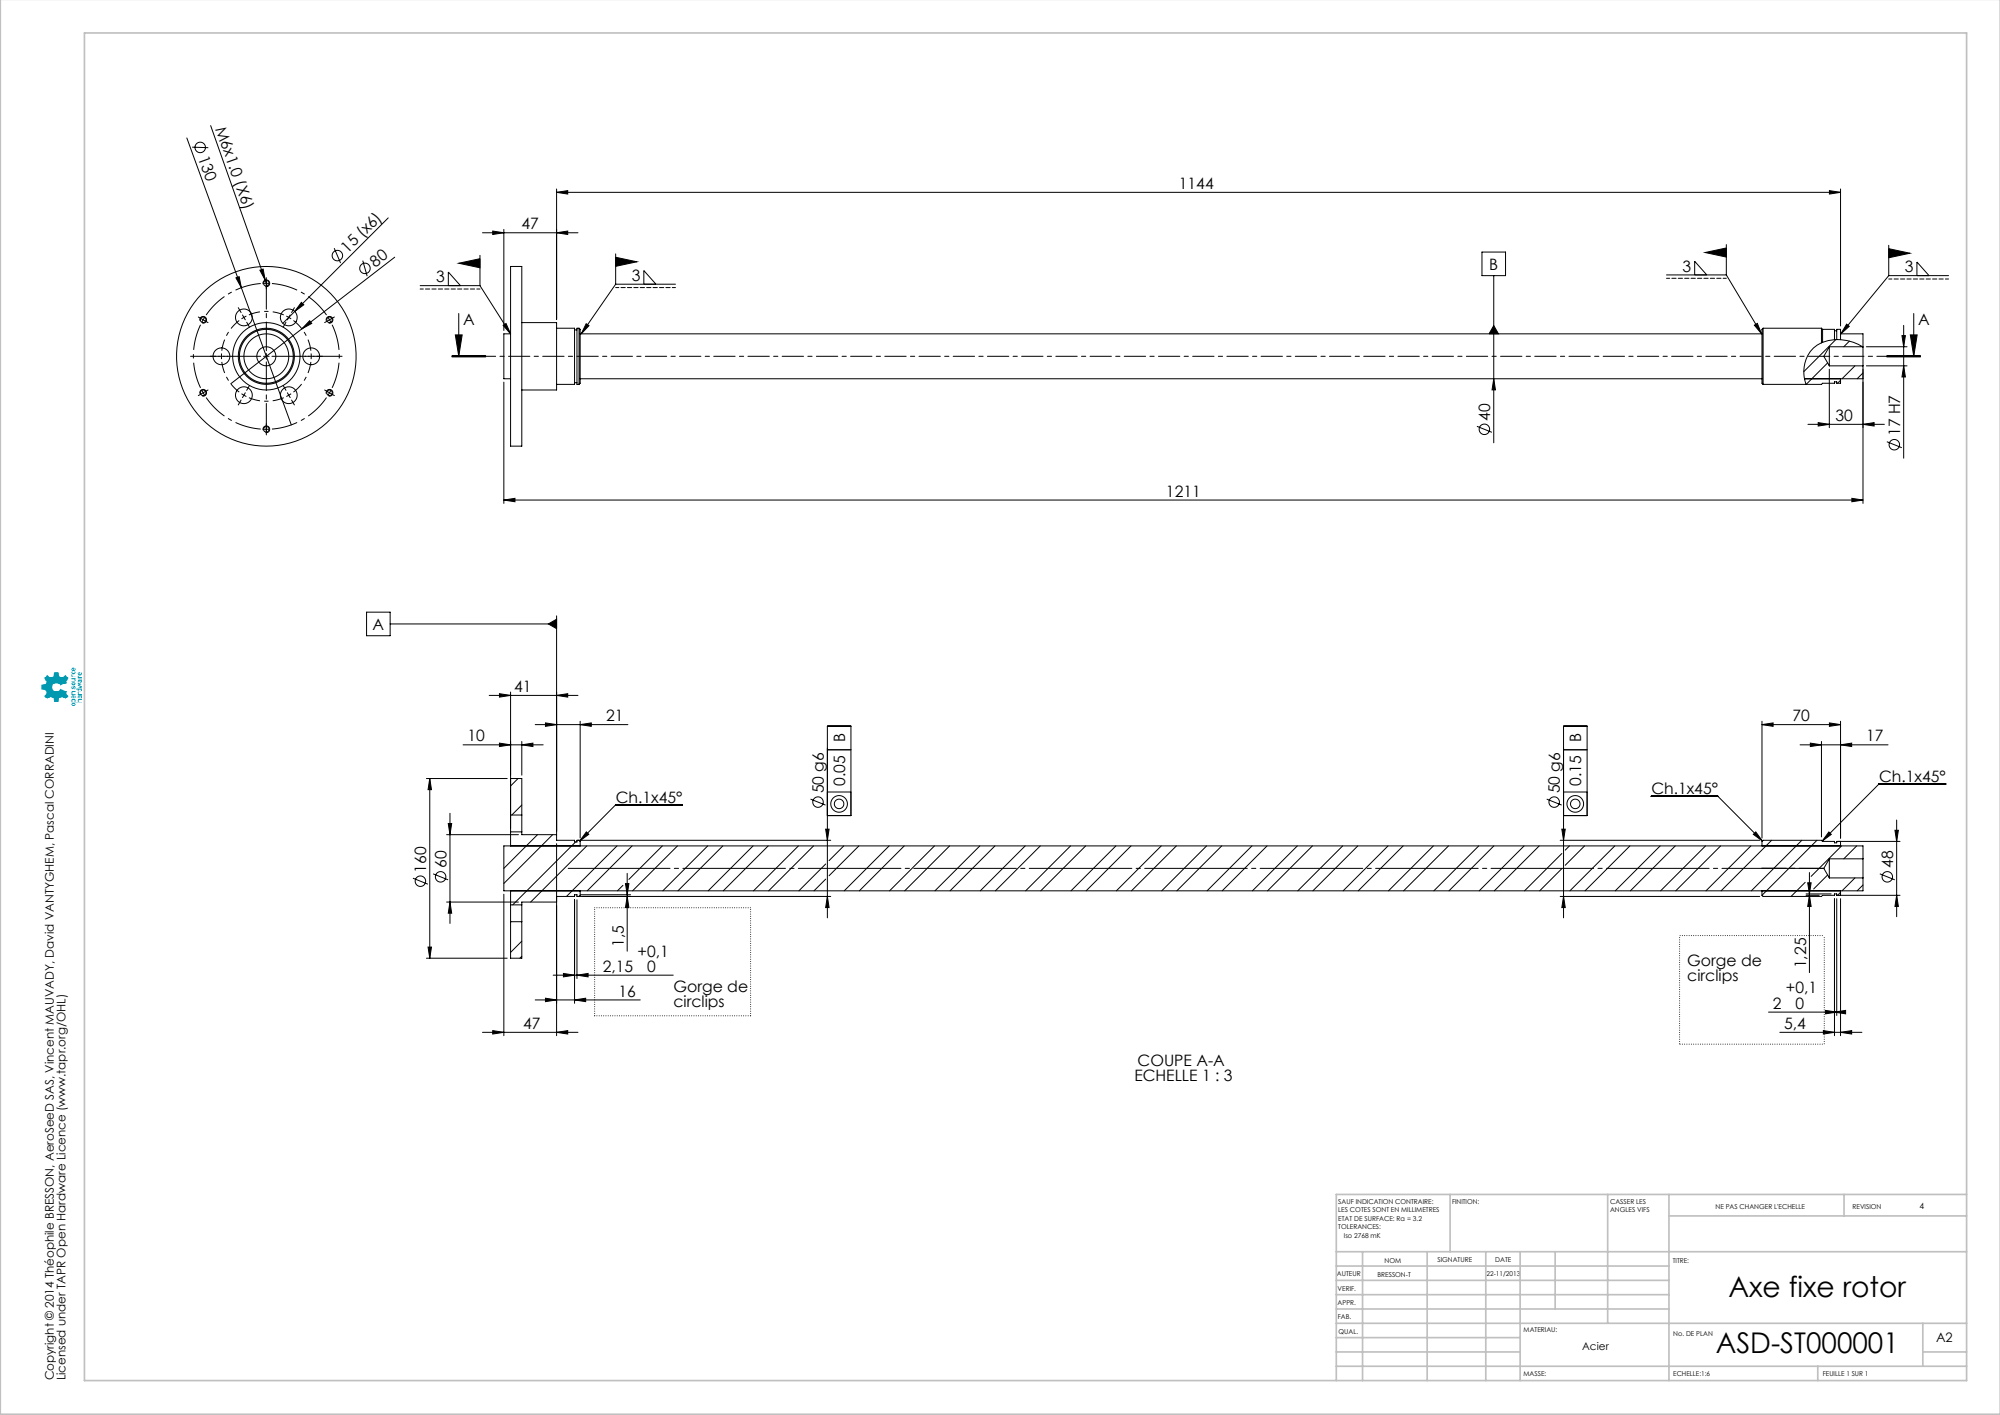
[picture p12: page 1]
COUPE A-A ECHELLE 1 : 3; Gorge de; ECHELLE:1:6; FEUILLE 1 SUR 1; NE PAS CHANGER L'ECHELLE; REVISION; CASSER LES ANGLES VIFS; SAUF INDICATION CONTRAIRE:; FINITION:

Copyright © 2014 Théophile BRESSON, AeroSeeD SAS, Vincent MAUVADY, David VANTYGHEM, Pascal CORRADINI

Licensed under TAPR Open Hardware Licence (www.tapr.org/OHL)

LES COTES SONT EN MILLIMETRES
ETAT DE SURFACE: Ra = 3.2
TOLERANCES:
Iso 2768 mK

NOM | SIGNATURE | DATE | | | | TITRE: Axe fixe rotor
QUAL. | | | | MATERIAU: Acier | ASD-ST000001 No. DE PLAN | A2

AUTEUR | BRESSON-T | | 22-11/2013
VERIF.
APPR.
FAB.

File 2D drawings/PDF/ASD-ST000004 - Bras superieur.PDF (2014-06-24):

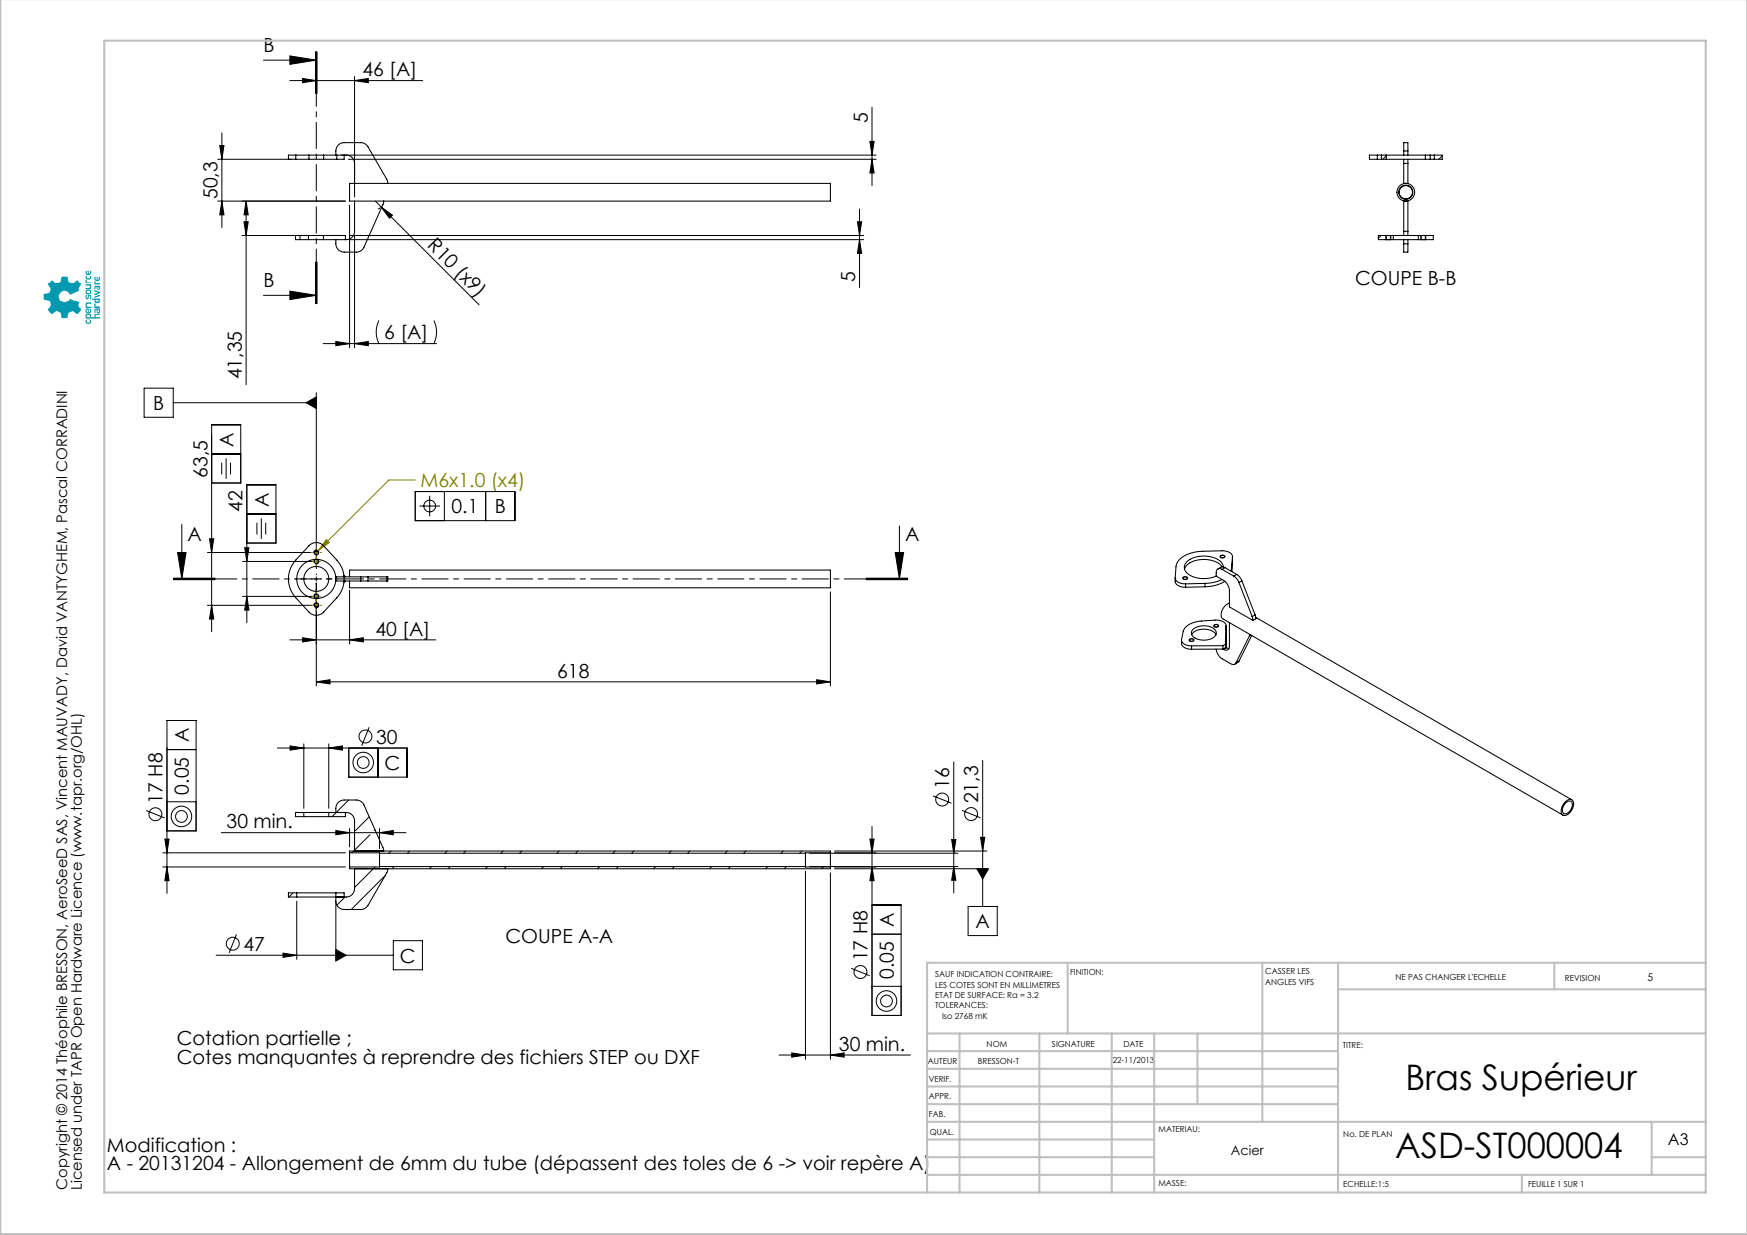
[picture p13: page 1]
30 min.; COUPE A-A; COUPE B-B; ECHELLE:1:5; FEUILLE 1 SUR 1; NE PAS CHANGER L'ECHELLE; REVISION; CASSER LES ANGLES VIFS

Copyright © 2014 Théophile BRESSON, AeroSeeD SAS, Vincent MAUVADY, David VANTYGHEM, Pascal CORRADINI

Licensed under TAPR Open Hardware Licence (www.tapr.org/OHL)

SAUF INDICATION CONTRAIRE:
LES COTES SONT EN MILLIMETRES
ETAT DE SURFACE: Ra = 3.2
TOLERANCES:
Iso 2768 mK

Cotation partielle ;
Cotes manquantes à reprendre des fichiers STEP ou DXF

NOM | SIGNATURE | DATE | | | | TITRE: Bras Supérieur
QUAL. | | | | MATERIAU: Acier | ASD-ST000004 No. DE PLAN | A3

AUTEUR | BRESSON-T | | 22-11/2013
VERIF.
APPR.
FAB.

Modification :
A - 20131204 - Allongement de 6mm du tube (dépassent des toles de 6 -> voir repère A)

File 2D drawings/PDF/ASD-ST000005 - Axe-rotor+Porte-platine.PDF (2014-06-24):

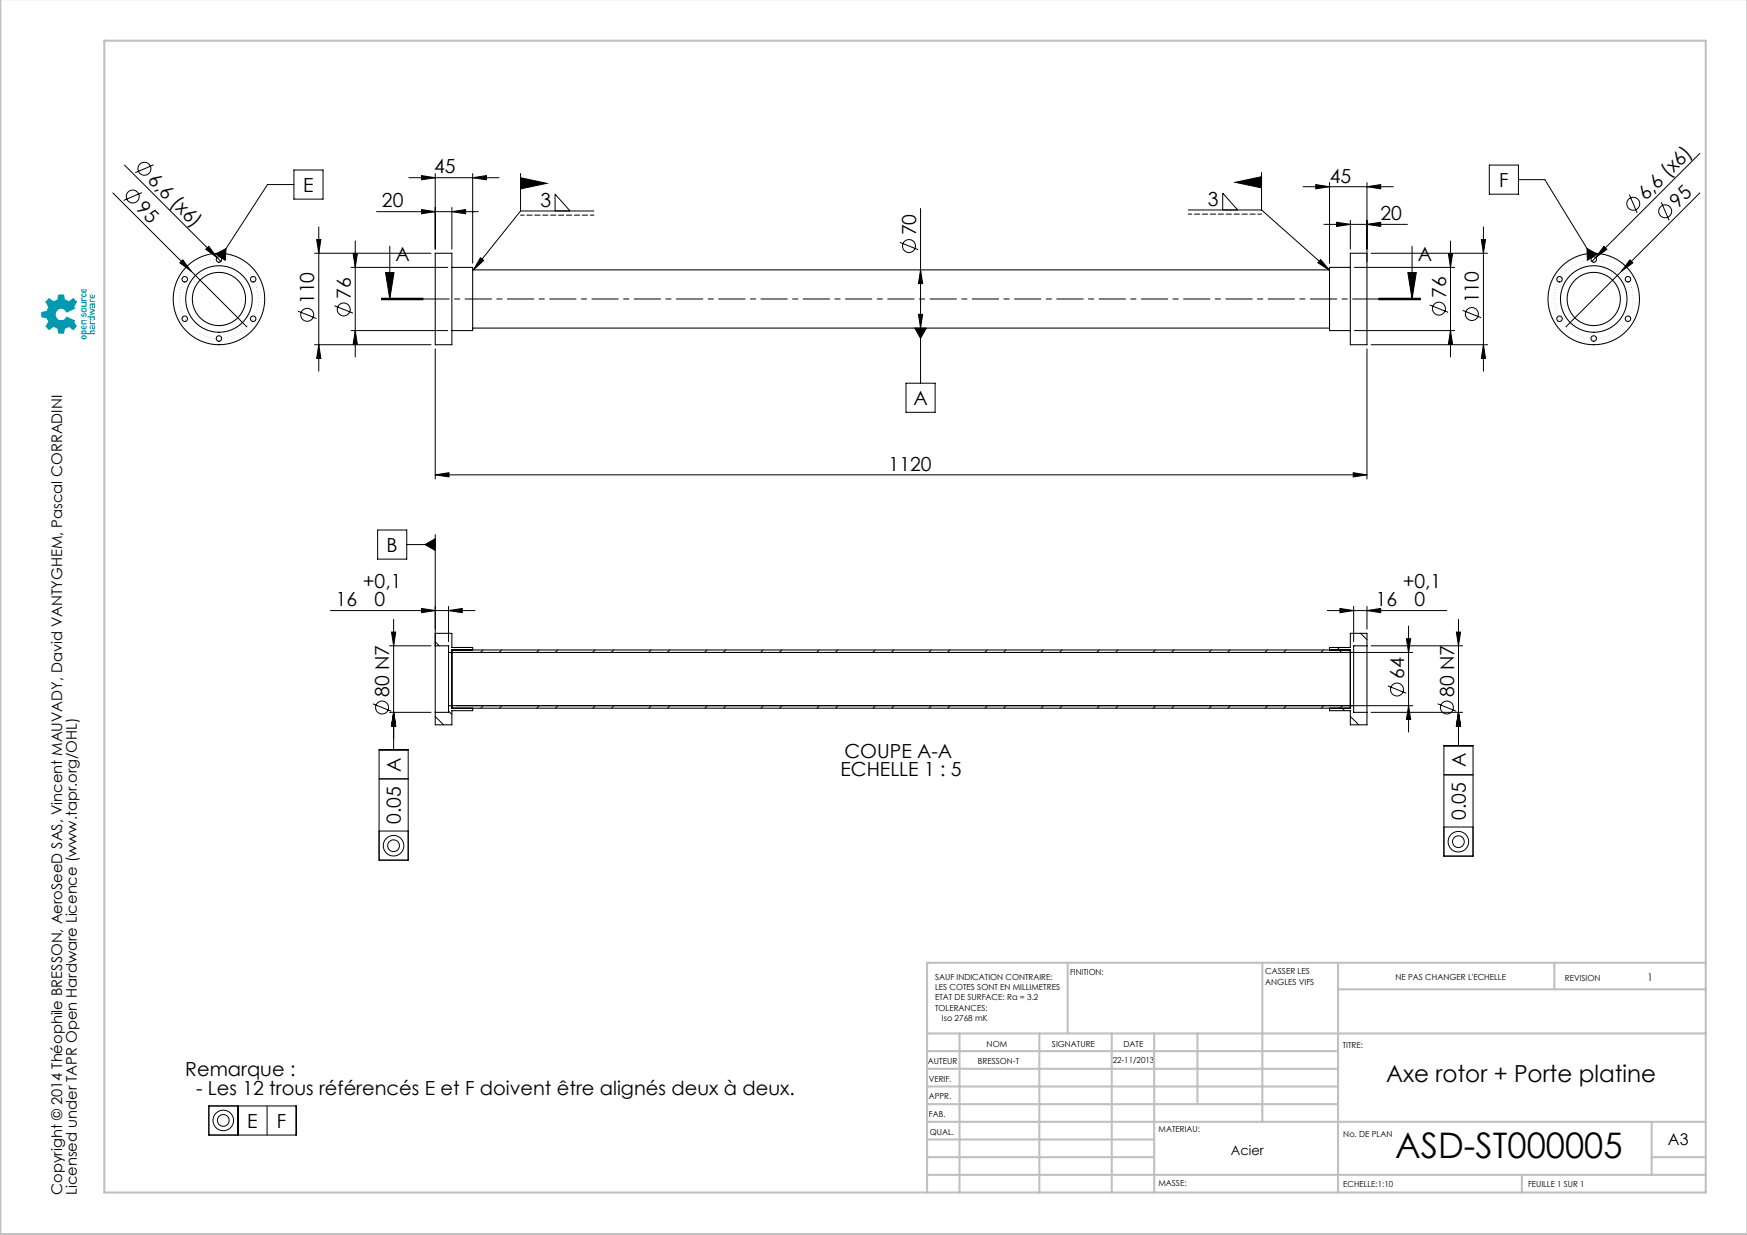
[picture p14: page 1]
COUPE A-A ECHELLE 1 : 5; ECHELLE:1:10; FEUILLE 1 SUR 1; NE PAS CHANGER L'ECHELLE; REVISION; CASSER LES ANGLES VIFS

Copyright © 2014 Théophile BRESSON, AeroSeeD SAS, Vincent MAUVADY, David VANTYGHEM, Pascal CORRADINI

Licensed under TAPR Open Hardware Licence (www.tapr.org/OHL)

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

NOM | SIGNATURE | DATE | | | | TITRE: Axe rotor + Porte platine
QUAL. | | | | MATERIAU: Acier | ASD-ST000005 No. DE PLAN | A3

Remarque :
- Les 12 trous référencés E et F doivent être alignés deux à deux.

AUTEUR | BRESSON-T | | 22-11/2013
VERIF.
APPR.
FAB.

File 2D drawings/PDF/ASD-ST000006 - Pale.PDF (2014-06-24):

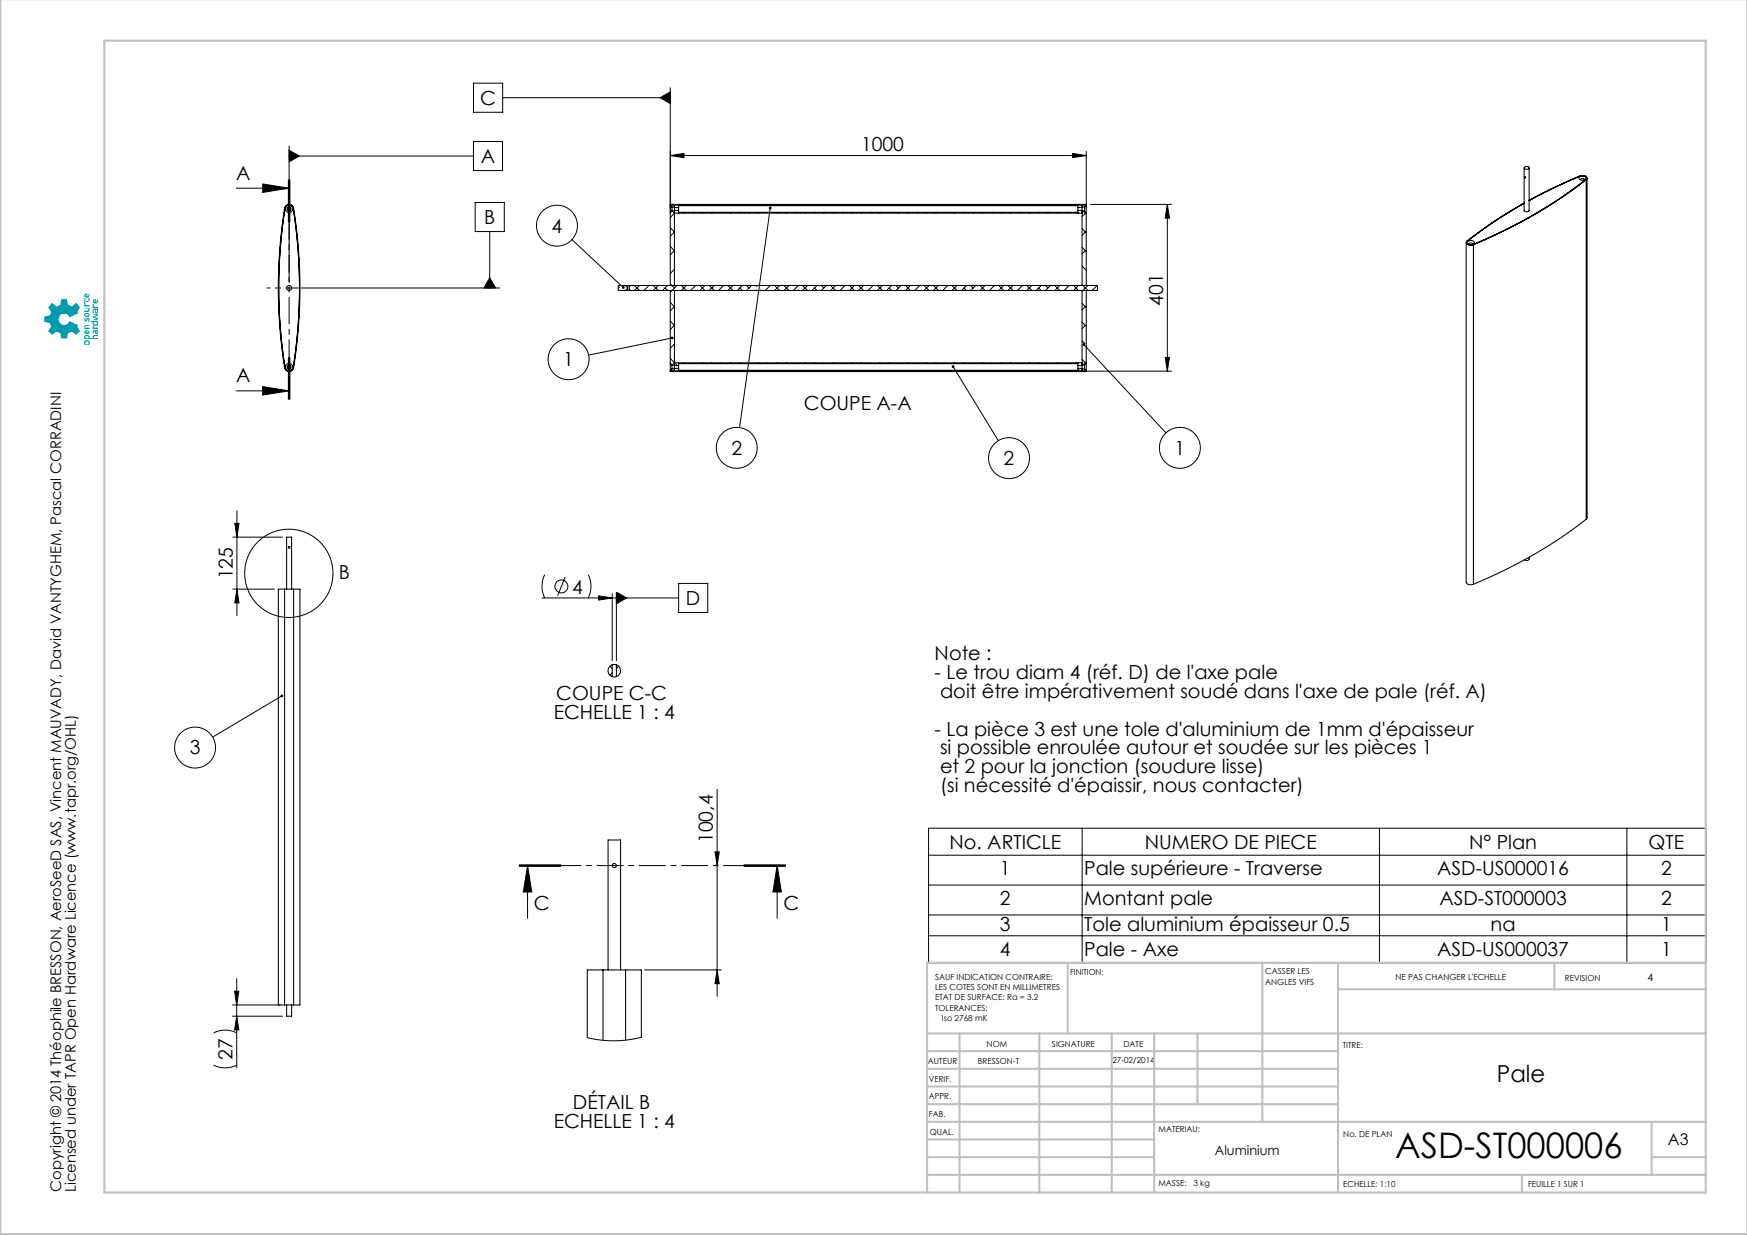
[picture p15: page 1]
COUPE A-A; DÉTAIL B ECHELLE 1 : 4; COUPE C-C ECHELLE 1 : 4; No. ARTICLE; NUMERO DE PIECE; N° Plan; QTE 1; Pale supérieure - Traverse; ASD-US000016; Montant pale; ASD-ST000003; Tole aluminium épaisseur 0.5; Pale - Axe; ASD-US000037; MASSE: 3 kg; ECHELLE: 1:10; FEUILLE 1 SUR 1; NE PAS CHANGER L'ECHELLE; REVISION; CASSER LES ANGLES VIFS

Copyright © 2014 Théophile BRESSON, AeroSeeD SAS, Vincent MAUVADY, David VANTYGHEM, Pascal CORRADINI

Note :
- Le trou diam 4 (réf. D) de l'axe pale
doit être impérativement soudé dans l'axe de pale (réf. A)
- La pièce 3 est une tole d'aluminium de 1mm d'épaisseur
si possible enroulée autour et soudée sur les pièces 1
et 2 pour la jonction (soudure lisse)
(si nécessité d'épaissir, nous contacter)

Licensed under TAPR Open Hardware Licence (www.tapr.org/OHL)

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

NOM | SIGNATURE | DATE | | | | TITRE: Pale
QUAL. | | | | MATERIAU: Aluminium | ASD-ST000006 No. DE PLAN | A3

AUTEUR | BRESSON-T | | 27-02/2014
VERIF.
APPR.
FAB.

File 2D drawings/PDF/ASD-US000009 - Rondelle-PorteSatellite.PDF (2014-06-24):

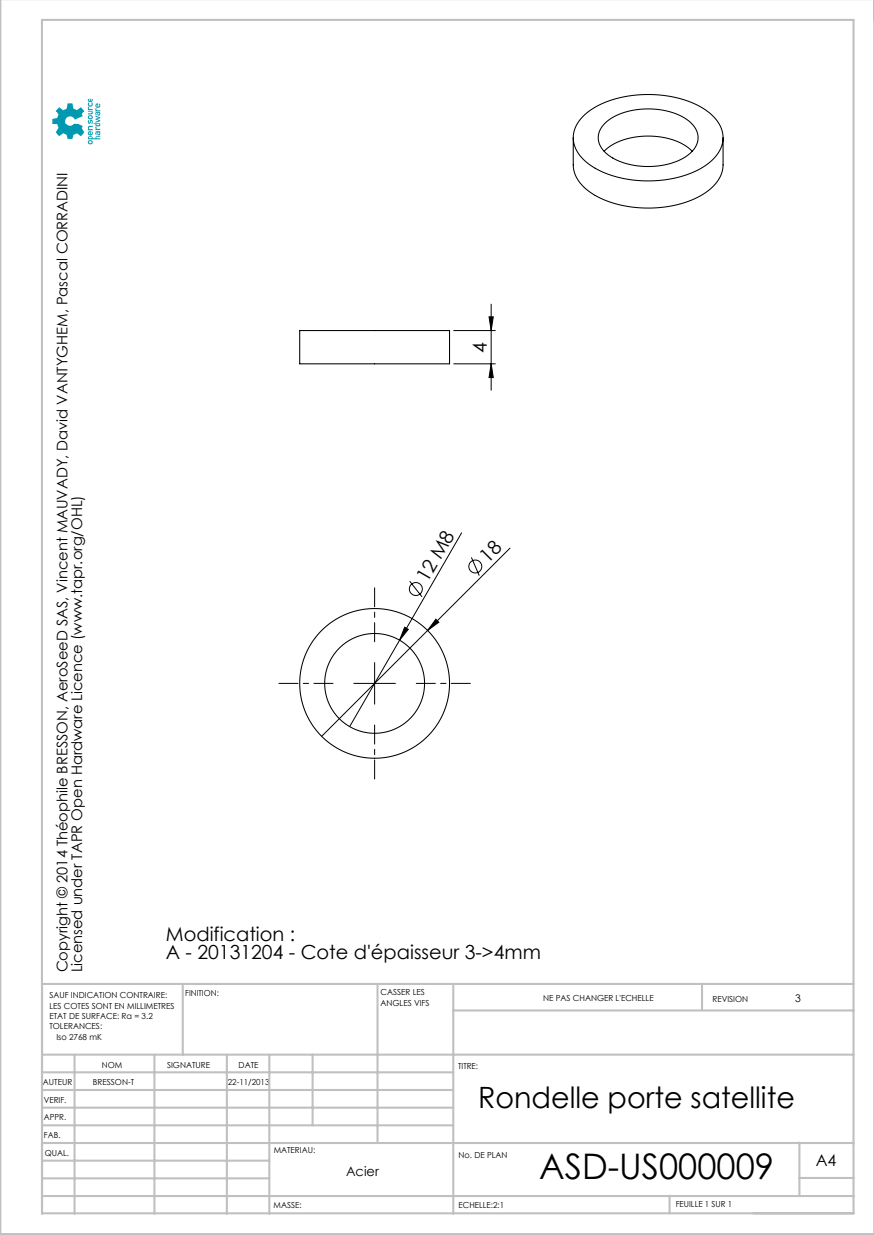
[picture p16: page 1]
Modification : A - 20131204 - Cote d'épaisseur 3->4mm; ECHELLE:2:1; FEUILLE 1 SUR 1; NE PAS CHANGER L'ECHELLE; REVISION; CASSER LES ANGLES VIFS

Copyright © 2014 Théophile BRESSON, AeroSeeD SAS, Vincent MAUVADY, David VANTYGHEM, Pascal CORRADINI

Licensed under TAPR Open Hardware Licence (www.tapr.org/OHL)

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

NOM | SIGNATURE | DATE | | | | TITRE: Rondelle porte satellite
QUAL. | | | | MATERIAU: Acier | ASD-US000009 No. DE PLAN | A4

AUTEUR | BRESSON-T | | 22-11/2013
VERIF.
APPR.
FAB.

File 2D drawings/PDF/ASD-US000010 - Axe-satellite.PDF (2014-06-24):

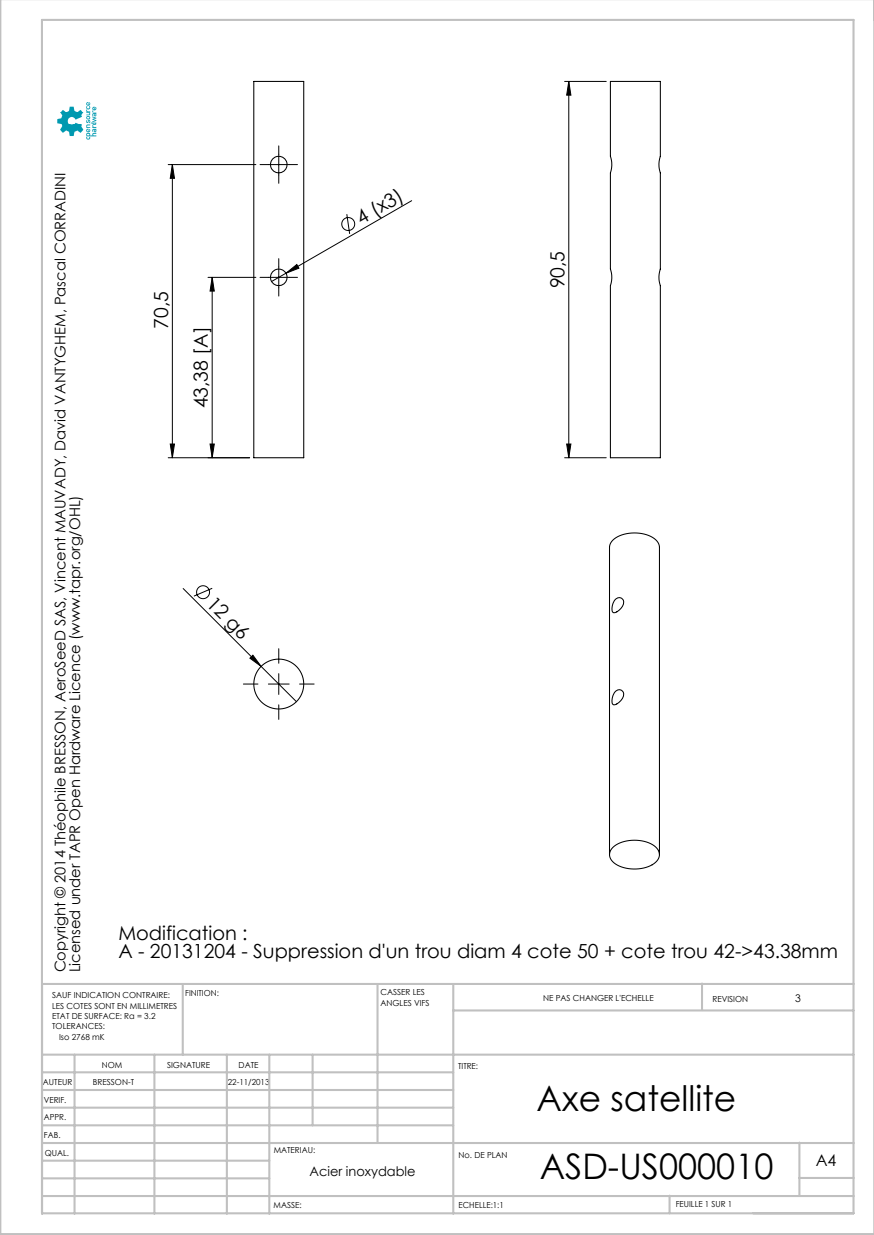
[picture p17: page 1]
ECHELLE:1:1; FEUILLE 1 SUR 1; NE PAS CHANGER L'ECHELLE; REVISION; CASSER LES ANGLES VIFS

Copyright © 2014 Théophile BRESSON, AeroSeeD SAS, Vincent MAUVADY, David VANTYGHEM, Pascal CORRADINI

Licensed under TAPR Open Hardware Licence (www.tapr.org/OHL)

Modification :
A - 20131204 - Suppression d'un trou diam 4 cote 50 + cote trou 42->43.38mm

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

NOM | SIGNATURE | DATE | | | | TITRE: Axe satellite
QUAL. | | | | MATERIAU: Acier inoxydable | ASD-US000010 No. DE PLAN | A4

AUTEUR | BRESSON-T | | 22-11/2013
VERIF.
APPR.
FAB.

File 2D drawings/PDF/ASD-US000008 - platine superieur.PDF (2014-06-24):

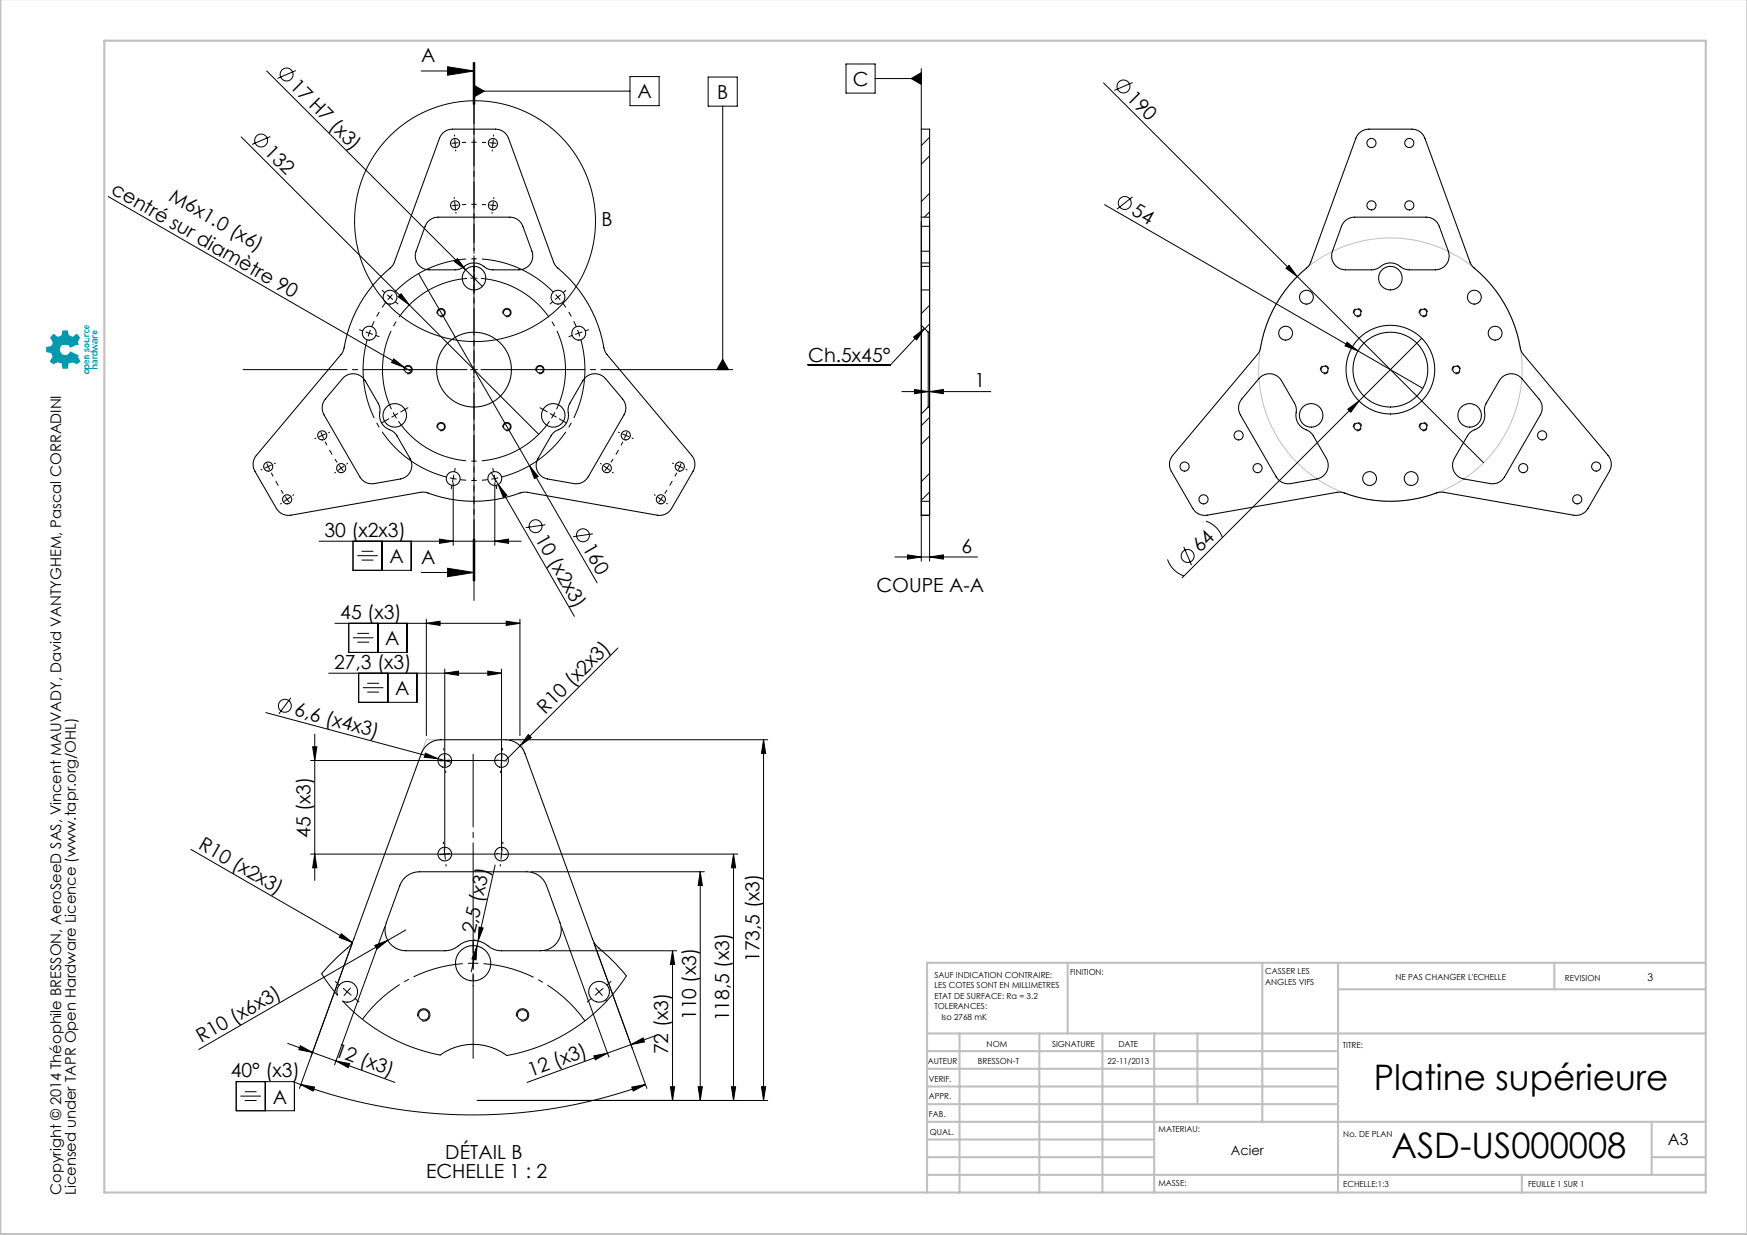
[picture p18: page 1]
COUPE A-A; DÉTAIL B ECHELLE 1 : 2; ECHELLE:1:3; FEUILLE 1 SUR 1; NE PAS CHANGER L'ECHELLE; REVISION; CASSER LES ANGLES VIFS

centré sur diamètre 90

Copyright © 2014 Théophile BRESSON, AeroSeeD SAS, Vincent MAUVADY, David VANTYGHEM, Pascal CORRADINI

Licensed under TAPR Open Hardware Licence (www.tapr.org/OHL)

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

NOM | SIGNATURE | DATE | | | | TITRE: Platine supérieure
QUAL. | | | | MATERIAU: Acier | ASD-US000008 No. DE PLAN | A3

AUTEUR | BRESSON-T | | 22-11/2013
VERIF.
APPR.
FAB.

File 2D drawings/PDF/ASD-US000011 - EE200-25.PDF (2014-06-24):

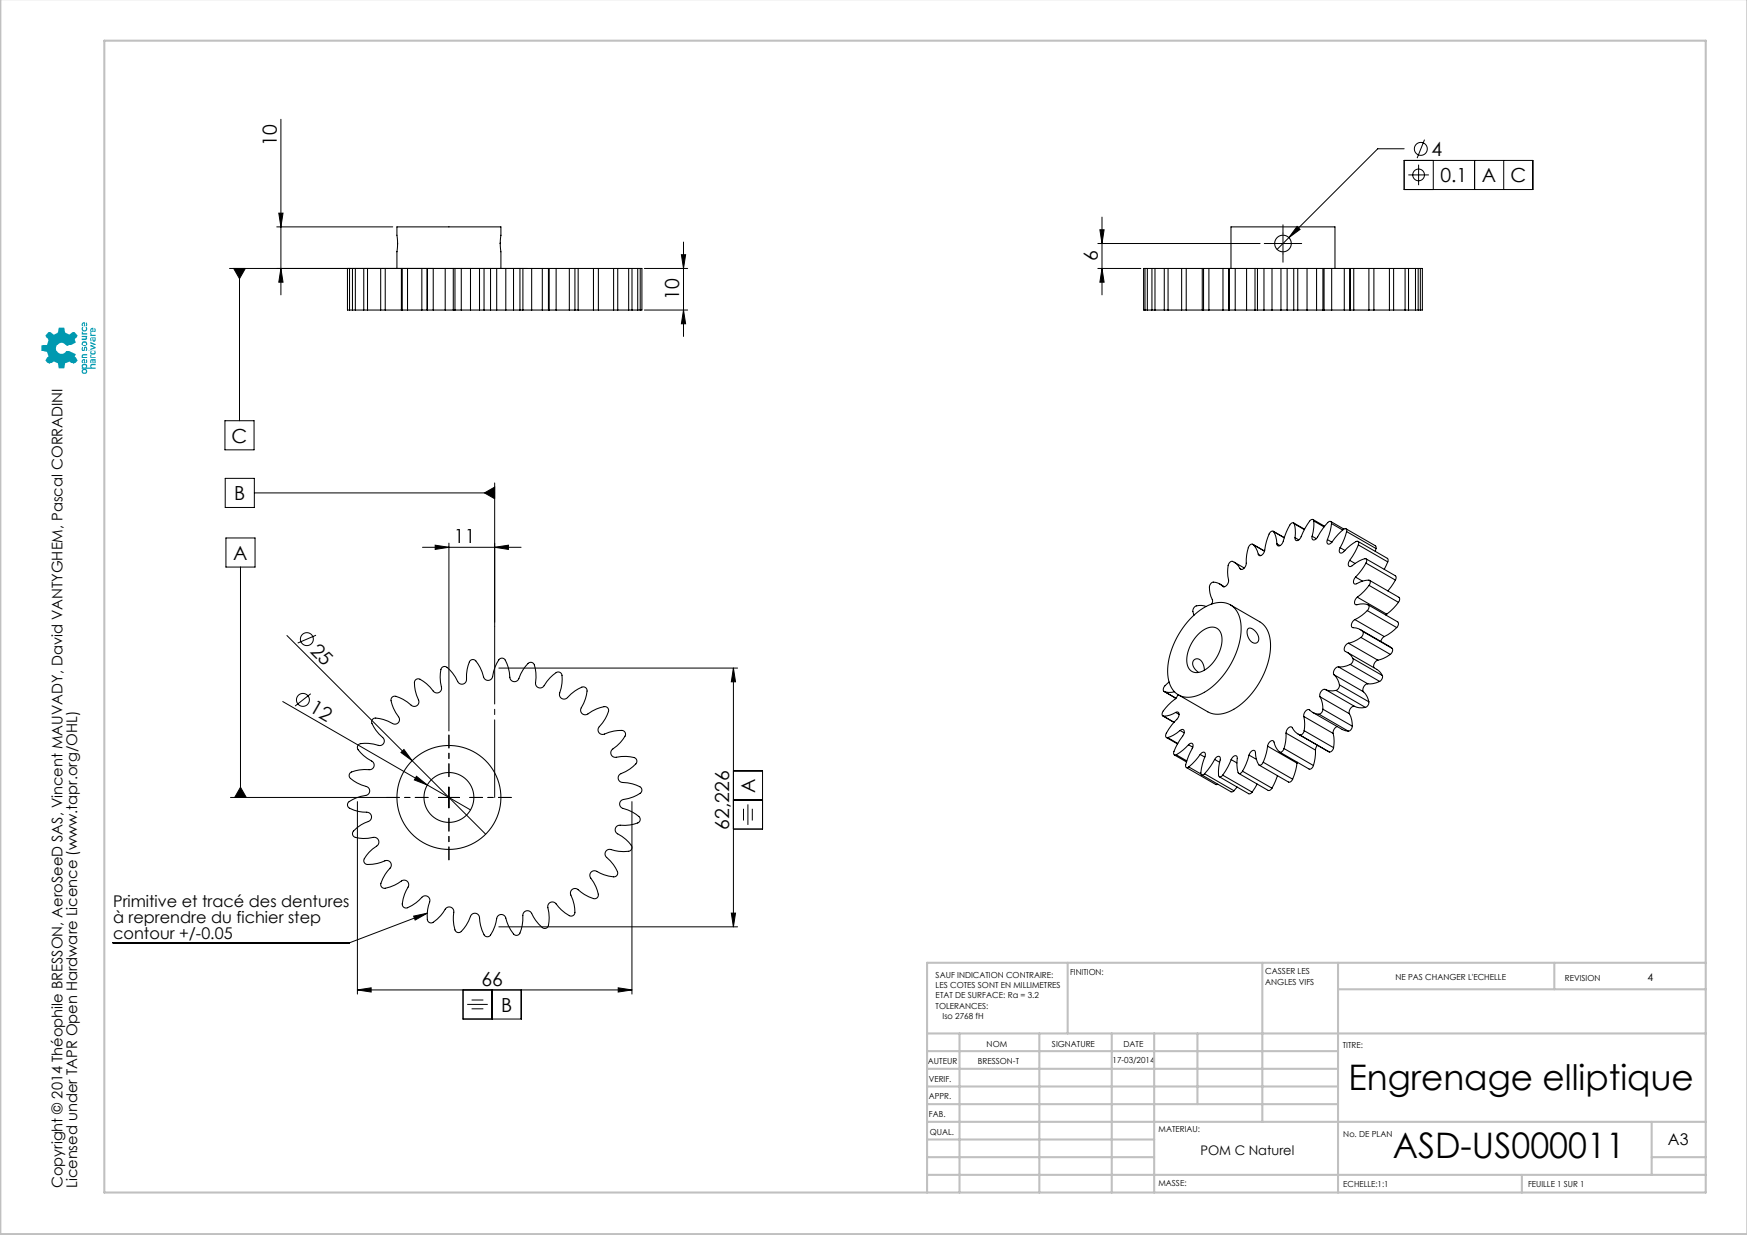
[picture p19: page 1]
ECHELLE:1:1; FEUILLE 1 SUR 1

Copyright © 2014 Théophile BRESSON, AeroSeeD SAS, Vincent MAUVADY, David VANTYGHEM, Pascal CORRADINI

Licensed under TAPR Open Hardware Licence (www.tapr.org/OHL)

Primitive et tracé des dentures
à reprendre du fichier step
contour +/-0.05

SAUF INDICATION CONTRAIRE: LES COTES SONT EN MILLIMETRES ETAT DE SURFACE: Ra = 3.2 TOLERANCES: Iso 2768 fH | FINITION: | CASSER LES ANGLES VIFS | NE PAS CHANGER L'ECHELLE | 4 REVISION
NOM | SIGNATURE | DATE | | | | TITRE: Engrenage elliptique
QUAL. | | | | MATERIAU: POM C Naturel | ASD-US000011 No. DE PLAN | A3

AUTEUR | BRESSON-T | | 17-03/2014
VERIF.
APPR.
FAB.

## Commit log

2014-04-02 tous les plan urbolienne 2013
2014-04-02 suppression plan rotor
2014-04-02 dépot de la licence TAPR
2014-04-02 labelisation et copyright des plans et dxf
    [ASD-ST000001 - Axe fixe rotor.DXF, ASD-ST000002 - Bras inferieur.DXF, ASD-ST000003 - Montant pale.DXF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]
2014-04-08 Ajout de la licence GNU ainsi que de la documentation de présentation de l'idée
    [traverse pale-superieure.DXF]
2014-04-08 Ajout de la licence GNU ainsi que la documentation de présentation de l'idée
    [ASD-ST000001 - Axe fixe rotor.DXF, ASD-ST000002 - Bras inferieur.DXF, ASD-ST000003 - Montant pale.DXF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]
2014-04-24 ajout docs
    [ASD-US000005 - Axe rotor.DXF, ASD-US000007 - porte platine superieur.DXF, ASD-US000017 - traverse pale-inferieure.DXF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]
2014-04-24 modification notice de montage
2014-04-24 suppression de la théorie de l'éolienne
2014-04-24 rename directories
    [ASD-ST000001 - Axe fixe rotor.DXF, ASD-ST000002 - Bras inferieur.DXF, ASD-ST000003 - Montant pale.DXF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]
2014-04-24 Rename DXf and PDF directories
    [ASD-ST000001 - Axe fixe rotor.DXF, ASD-ST000002 - Bras inferieur.DXF, ASD-ST000003 - Montant pale.DXF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]
2014-04-25 Modification CAO du régulateur mécanique
    [ASD-US000032 - Axe-satellite-differentiel.DXF, ASD-US000038 - Rondelle7-5.DXF, ASD-US000039 - Engrenage-conique-girouette.DXF]
2014-04-25 modification de la notice
2014-05-12 mise à jour des plans
    [ASD-ST000001 - Axe fixe rotor.DXF, ASD-ST000002 - Bras inferieur.DXF, ASD-ST000003 - Montant pale.DXF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]
2014-06-24 suppression systeme de securite
    [ASD-ST000001 - Axe fixe rotor.DXF, ASD-ST000002 - Bras inferieur.DXF, ASD-ST000003 - Montant pale.DXF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]
2014-06-24 Ajout doc de description du fonctionnement
